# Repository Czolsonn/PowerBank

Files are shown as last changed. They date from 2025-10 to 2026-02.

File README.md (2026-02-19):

# STM32 Solar PowerBank





Projekt inteligentnego PowerBanka sterowanego mikrokontrolerem z rodziny **STM32F1**, integrującego ładowanie fotowoltaiczne z zaawansowanym zarządzaniem energią.

## 📋 Opis Projektu

Urządzenie łączy funkcję magazynu energii (ogniwa 18650) z inteligentnym systemem sterowania. Wykorzystuje synchroniczną przetwornicę Buck do efektywnego obniżania napięcia oraz dedykowane kontrolery USB do bezpiecznego ładowania urządzeń zewnętrznych.

### Kluczowe parametry techniczne
* **Mikrokontroler:** STM32F1xx (zarządzanie PWM, pomiary ADC, komunikacja).
* **Wejście:** Obsługa paneli fotowoltaicznych i zewnętrznych źródeł DC.
* **Wyjście:** Porty USB sterowane przez układy TPS25810 oraz TPS2514.
* **Pomiary:** Monitorowanie prądu za pomocą wzmacniacza INA180A2.

## 📂 Struktura Projektu

Repozytorium jest podzielone na sekcje sprzętową, programową oraz dokumentacyjną:

```text
.
├── 📂 Dokumentacja_peryferiów  # Noty katalogowe i opisy układów (TPS, INA, LM)
├── 📂 Obudowa_Schemat          # Pliki projektowe obudowy i poglądowe schematy
├── 📂 PowerBank_KICAD          # Projekt PCB w programie KiCad
│   ├── 📂 production           # Pliki produkcyjne (Gerber, BOM, OZE_PowerBank)
│   └── 📂 backups              # Kopie zapasowe projektu elektroniki
└── 📂 STM_C                    # Warstwa oprogramowania (Firmware)
    └── 📂 PowerBank            # Główny projekt STM32CubeIDE
        ├── 📂 Core             # Kod źródłowy aplikacji (Inc, Src, Startup)
        ├── 📂 Drivers          # Biblioteki HAL i CMSIS
        └── 📂 Debug            # Pliki binarne i logi kompilacji

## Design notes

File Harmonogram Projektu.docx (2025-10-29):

Harmonogram Projektu - PowerBank

1. Schemat układu wraz z doborem elementów wraz z symulacjami – (28.10 - 5.11)
2. Schemat PCB – (5.11 – 12.11) – zamówienie elementów i płytki
3. Oprogramowanie STM32 – (26.11 – 3.12)
4. Lutowanie układu i zgrzewanie ogniw (10.12 – 17.12)
5. Projekt i druk obudowy (07.01)
6. Dokumentacja i złożenie wszystkiego w całość wraz z testami (18.01)

Hubert Polus 278308

Michał Zawada

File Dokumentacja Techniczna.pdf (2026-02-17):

## Dokumentacja Powerbanka

Michał Zawada, Hubert Polus

3 lutego 2026

## Spis treści

1 Założenia projektowe | 3
2 Zdjęcie urządzenia | 3
3 Panel Fotowoltaiczny | 3
4 Schematy i opis poszczególnych funkcjonalnych elementów składowych. | 3

4.2 LM5106 - sterownik bramek MOSFET typu N do synchronicznego konwer-

4.5.1 | TPS2514ADBVT – kontroler dedykowanego portu ładowania USB . | 6
4.5.2 | TPS25810RVCR – kontroler portu USB z funkcją ładowania . . . . | 6
5 Przepływ Energii w układzie | 7
6 PCB | | 7
7 Algorytm sterowania | 8
8 Obliczenia | 10
9 Weryfikacja eksperymentalna układu | 11
10 Budżet Projektu | 13

11 Wnioski końcowe | 13
12 Linki i inspiracje | 14

## 1 Założenia projektowe

- Główna funkcja urządzenia: przenośne źródło zasilania dla urządzeń USB, ładowanie w standardzie BC1.2 z wyprowadzonym złączem USB A oraz USB C.
- Moduły: panel solarny, buck converter, procesor STM32F103C8Tx, TPS25810RVCR USB charging module, układ BMS, zewnętrzne przetwronice DC-DC.

## 2 Zdjęcie urządzenia

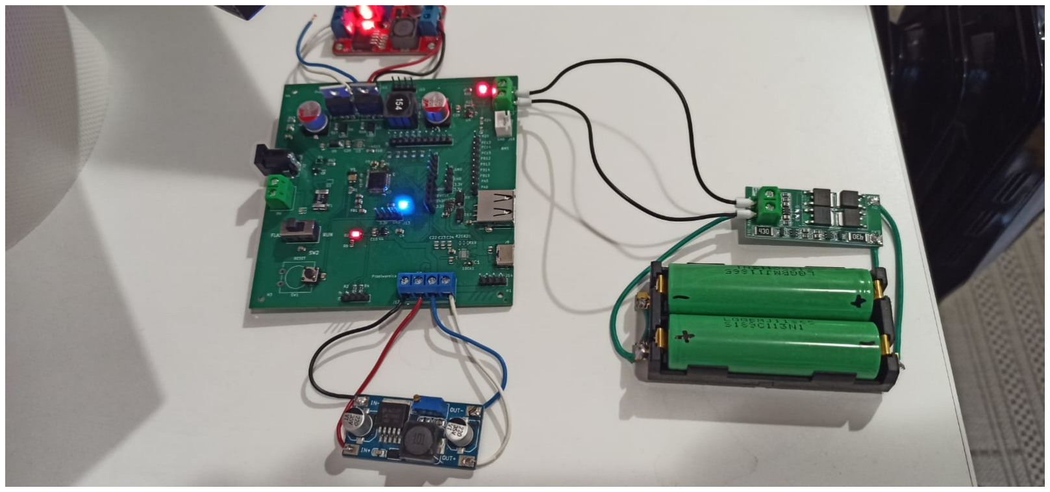
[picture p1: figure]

Rysunek 1: PowerBank - zaprojektowana płytka wraz z przetwornicami i pakietem ogniw.

## 3 Panel Fotowoltaiczny

Poniżej podane zostały główne parametry panelu fotowoltaicznego który zostanie wykorzystany w projekcie.

- P = 5W
- Impp = 0.3A
- Vmpp = 16.8V
- Isc = 0.34A
- Voc = 21.0V

## 4 Schematy i opis poszczególnych funkcjonalnych ele-

mentów składowych.

### 4.1 Buck Converter - Przetwornica Synchroniczna

- Vin = 15 − 30V

- IinMAX = 0.5A
- PWM Frequency fs = 100kHz
- Algorytm sterowania iteracyjny na STM32.
- Vout = 8.4V oddawane do BMS.
- PinMAX = 15W

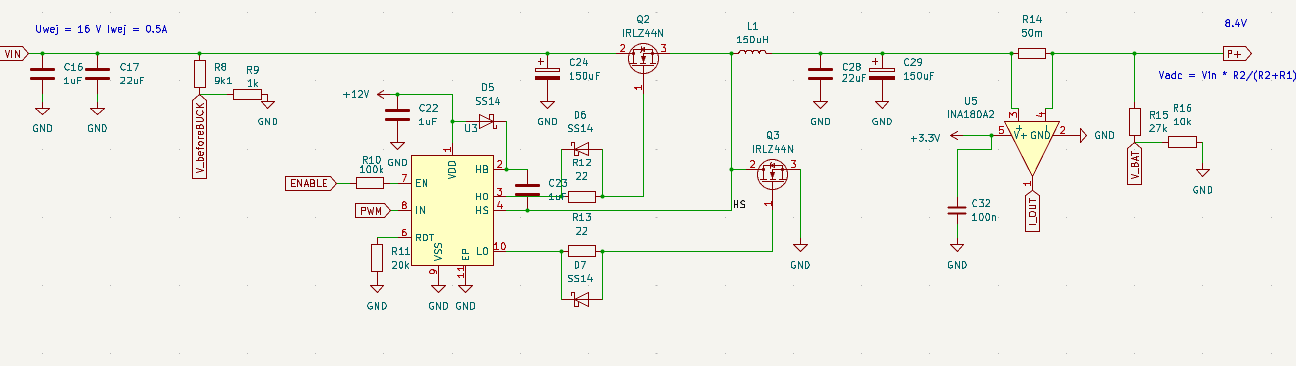
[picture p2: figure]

Rysunek 2: Schemat układu przetwornicy

Układy scalone zastosowane w układzie przetwornicy synchronicznej

### 4.2 LM5106 - sterownik bramek MOSFET typu N do synchro-

nicznego konwertera obniżającego napięcie

LM5106 jest dwukanałowym sterownikiem bramek tranzystorów MOSFET typu highside oraz low-side, przeznaczonym do zastosowań w impulsowych układach zasilania. Układ umożliwia sterowanie parą tranzystorów MOSFET za pomocą pojedynczego sygnału PWM oraz zapewnia automatyczne generowanie odpowiedniego czasu martwego (dead-time) pomiędzy przełączeniami tranzystorów. W realizowanym projekcie LM5106 został zastosowany jako element sterujący synchronicznym przekształtnikiem obniżającym napięcie typu buck (step-down).

### 4.3 INA180A2 - wzmacniacz operacyjny do pomiarów prądu

INA180A2 jest układem przeznaczonym do pośredniego pomiaru prądu poprzez wzmacnianie spadku napięcia odkładającego się na rezystorze pomiarowym (shunt). W omawianej wersji układu zastosowano wzmocnienie równe 20 V/V, natomiast na jego wyjściu dostępny jest analogowy sygnał napięciowy proporcjonalny do mierzonego prądu.

### 4.4 Schemat STM32

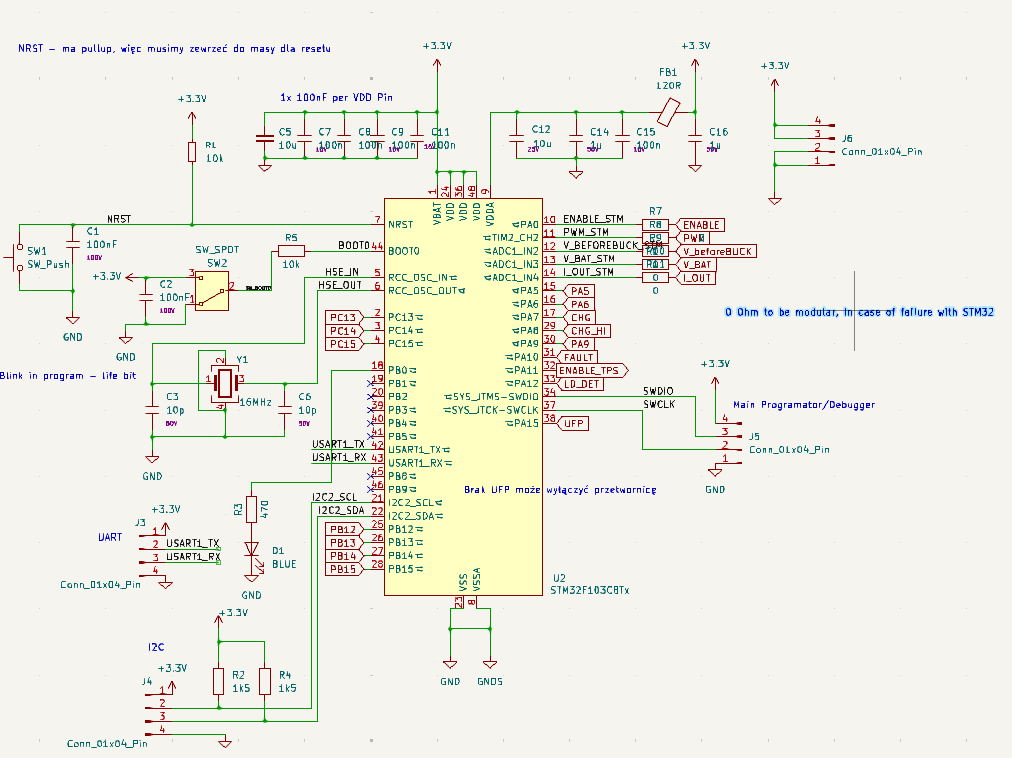
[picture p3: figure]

Rysunek 3: Schemat części dotyczącej mikrokontrolera STM32.

4.4.1 Opis części układu związanej z mikroprocesorem.

W projekcie wykorzystano mikroprocesor STM32F103C8Tx. Dołożono zewnętrzny rezonator kwarcowy oraz przycisk do resetu i wyboru FLASH/RUN. Aby sygnalizować pracę i wykonywanie programu, dołożono diodę niebieską LED, która miga z okresem T=1s. Programowanie płytki PowerBank umożliwia interfejs SWD ST-LINK/V2, którego piny zostały wyprowadzone na płytce. Większość pinów mikrokontrolera została wyprowadzona w celu umożliwienia debugowania - sygnały związane z kontrolerem ładowania portu USB, przetwornicą oraz pozostałe, które mogą zostać użyte do rozbudowania funkcjonalności układu.

4.5

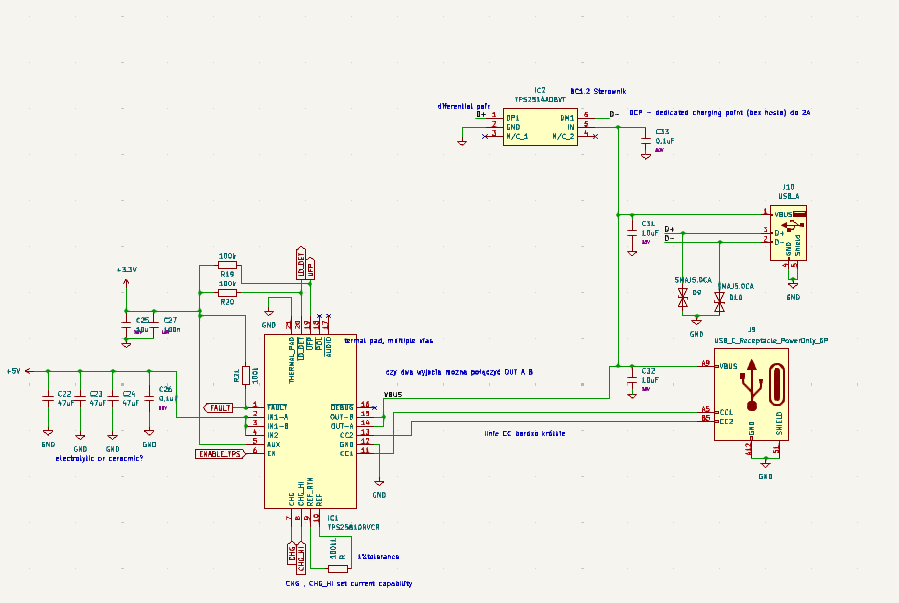
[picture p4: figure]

Rysunek 4: Schemat części dotyczącej układów ładowania USB

Opis zastosowanych układów scalonych.

### 4.5.1 TPS2514ADBVT – kontroler dedykowanego portu ładowania USB

Układ TPS2514ADBVT jest kontrolerem przeznaczonym do implementacji dedykowanego portu ładowania (DCP) zgodnego ze standardem USB BC1.2. Jego głównym zadaniem jest odpowiednia konfiguracja linii danych, tak aby podłączone urządzenie (np. smartfon lub tablet) mogło rozpoznać port jako port ładowania o podwyższonej wydajności prądowej.

### 4.5.2 TPS25810RVCR – kontroler portu USB z funkcją ładowania

Układ TPS25810RVCR firmy Texas Instruments jest zintegrowanym kontrolerem portu USB, przeznaczonym głównie do zastosowań w systemach zasilania i ładowania urządzeń przenośnych. Układ ten obsługuje standard USB Battery Charging (BC1.2), umożliwiając automatyczne rozpoznawanie typu podłączonego urządzenia oraz dostosowanie dopuszczalnego prądu ładowania.
TPS25810 zawiera wbudowany przełącznik mocy, zabezpieczenia nadprądowe, nadnapięciowe oraz termiczne, co pozwala na bezpieczne zasilanie urządzeń USB bez konieczności stosowania dodatkowych elementów ochronnych. Układ może pracować w trybie autonomicznym lub być sterowany przez mikrokontroler za pomocą interfejsu I²C, co umożliwia monitorowanie stanu portu oraz dynamiczne zarządzanie zasilaniem.
Do wyjść cyfrowych zastosowano odpowiednie rezystory podciągające zgodne z dokumentacją oraz dodano kondensatory odsprzęgające.

## 5 Przepływ Energii w układzie

- Schemat przepływu energii: Panel fotowoltaiczny → Buck converter → BMS → Ogniwo LiPol → Przetwornica Step-Down → port USB.

## 6 PCB

### 6.1 Zastosowanie ścieżek o zróżnicowanej szerokości

W projekcie płytki drukowanej zastosowano ścieżki o różnych szerokościach, w zależności od pełnionej funkcji elektrycznej. Ścieżki zasilające oraz linie przenoszące większe prądy zostały zaprojektowane o zwiększonej szerokości w celu ograniczenia spadków napięcia oraz strat mocy. Linie sygnałowe, w tym sygnały sterujące i komunikacyjne, prowadzone są węższymi ścieżkami, co pozwala na efektywne wykorzystanie powierzchni PCB oraz zachowanie odpowiednich odstępów izolacyjnych.

### 6.2 Struktura czterowarstwowej płytki PCB

Płytka została zaprojektowana jako czterowarstwowa, co umożliwiło poprawę integralności sygnałów oraz uporządkowanie dystrybucji zasilania.

### 6.3 Podział funkcjonalny płytki

Układ elementów na PCB został wykonany z zachowaniem podziału funkcjonalnego. Poszczególne bloki, takie jak sekcja zasilania, kontroler portu USB, przetwornica oraz złącza wyjściowe, zostały rozłożone w sposób minimalizujący długości ścieżek, ale pozwalający podzielić płytkę na części funkcjonalne.

### 6.4 Zastosowanie rezystorów 0

W projekcie wykorzystano rezystory 0 pełniące rolę konfiguracyjną. Elementy te umożliwiają odlutowanie sygnałów sterujących od mikroprocesora i sterowanie przetwornicą z zewnętrznego układu.

6.5 Odpowiednie poprowadzenie linii różnicowych.

Linie USB D+ i D zostały poprowadzone jako para różnicowa, z zachowaniem jednakowej długości, stałej szerokości ścieżek oraz kontrolowanego odstępu pomiędzy nimi. Ścieżki te prowadzone są nad ciągłą płaszczyzną masy, bez przerw w płaszczyźnie, co zapewnia kontrolę impedancji oraz minimalizację odbić i przesłuchów. Unikano ostrych zakrętów oraz niepotrzebnych przelotek na trasie sygnałów.

## 7 Algorytm sterowania

### 7.1 Konfiguracja mikrokontrolera w środowisku STM32CubeMX

Wstępna konfiguracja warstwy sprzętowej mikrokontrolera STM32F103C8Tx została zrealizowana przy użyciu oprogramowania STM32CubeMX. Schemat wyprowadzeń (pinout) układu przedstawiono na Rysunku 5

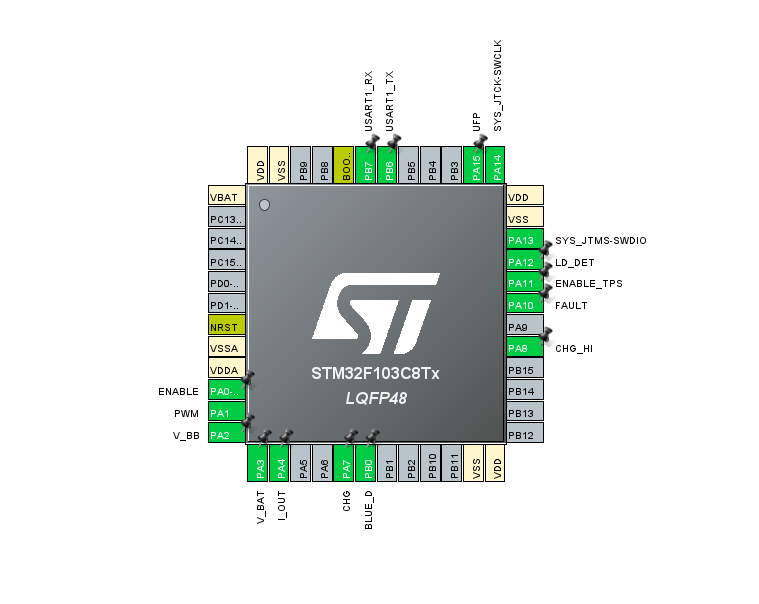
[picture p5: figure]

Rysunek 5: Pinout

Do kluczowych ustawień konfiguracyjnych projektu należą:

- System zegarowy: Jako źródło sygnału taktującego wybrano wewnętrzny oscylator RC (HSI – High Speed Internal). Decyzja ta podyktowana była ograniczeniami sprzętowymi dotyczącymi zewnętrznego rezonatora kwarcowego. Częstotliwość zegara systemowego (SYSCLK) została ustalona na poziomie 64 MHz z wykorzystaniem pętli fazowej PLL (Phase Locked Loop). Schemat drzewa zegarowego widoczny jest na Rysunku 6.
- Modulacja PWM: Timer sterujący generacją sygnału PWM skonfigurowano na częstotliwość pracy 100 kHz. Przy przyjętym taktowaniu rdzenia pozwoliło to na uzyskanie rozdzielczości wypełnienia wynoszącej 640 kroków.
- Przetwornik ADC: Akwizycja danych analogowych realizowana jest z wykorzystaniem mechanizmu bezpośredniego dostępu do pamięci (DMA) w trybie ciągłym (Continuous Conversion Mode). Dobrano następujące czasy próbkowania dla mierzonych wielkości fizycznych:

– Napięcie wejściowe i wyjściowe przetwornicy: 55.5 cykli zegara.
– Prąd wyjściowy przetwornicy: 239.5 cykli zegara.

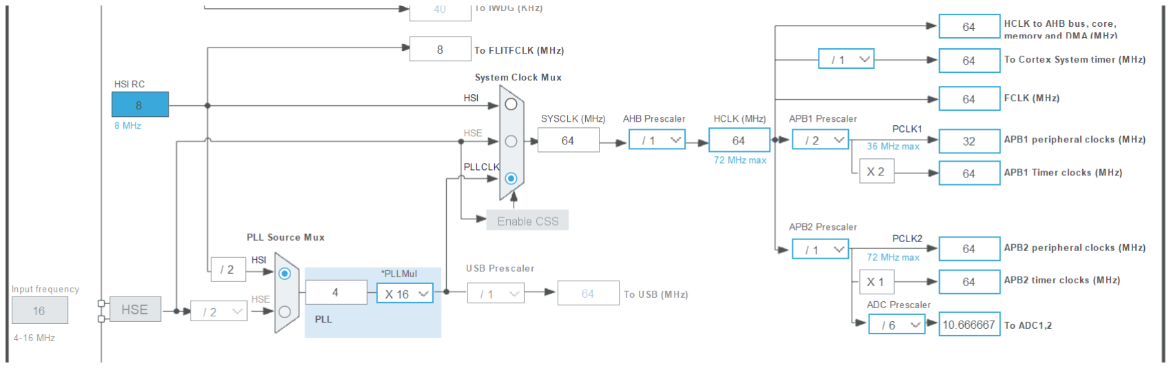
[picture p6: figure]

Rysunek 6: Taktowanie procesora

### 7.2 Implementacja oprogramowania w środowisku STM32CubeIDE

Kod źródłowy sterujący procesem ładowania ogniw oraz zarządzający układem peryferyjnym został zaimplementowany w środowisku STM32CubeIDE. Architektura oprogramowania opiera się na cyklicznym wykonywaniu zadań w dwóch głównych domenach czasowych:

1. Pętla sterowania i logiki (100 Hz) – odpowiedzialna za krytyczne procesy obliczeniowe i decyzyjne.
2. Pętla interfejsu i diagnostyki (1 Hz) – realizująca zadania o niższym priorytecie czasowym (sygnalizacja, komunikacja).

Szczegółowy opis procesów pętli głównej (100 Hz)

W ramach pętli szybkiej realizowane są dwa kluczowe bloki funkcjonalne:

1. Akwizycja i kondycjonowanie sygnałów pomiarowych (ADC) Proces ten składa się z trzech etapów zapewniających stabilność odczytów:
- Wyznaczenie średniej arytmetycznej z bufora 20 próbek pomiarowych.
- Konwersja surowych danych na jednostki fizyczne (skalowanie napięć i prądów).
- Filtracja cyfrowa z wykorzystaniem filtru dolnoprzepustowego o nieskończonej odpowiedzi impulsowej – wykładniczej średniej kroczącej (EMA).
2. Algorytm sterowania i bezpieczeństwa Logika sterująca pracą ładowarki oparta jest na:
- Weryfikacji zabezpieczeń: Ciągłe monitorowanie przekroczenia wartości granicznych dla napięcia (OVP) oraz prądu (OCP) w celu ochrony układu i ogniwa.
- Maszynie Stanów (FSM): Automatyczne przełączanie trybów pracy układu w zależności od warunków panujących w obwodzie. Zaimplementowane stany to: IDLE (oczekiwanie), SOFT START (łagodny rozruch), CHARGING (ładowanie właściwe wraz z algorytmem MPPT) oraz ERROR (stan błędu).

Szczegółowy opis pętli pomocniczej (1 Hz)

Pętla wolna odpowiada za interakcję z użytkownikiem oraz nadzór nad procesem:

- UART: Cykliczna transmisja danych diagnostycznych (monitorowanie napięć, prądów oraz mocy chwilowej) do terminala zewnętrznego.
- Sygnalizacja stanu: Obsługa diod LED informujących o statusie pracy urządzenia.

## 8 Obliczenia

### 8.1 Dobór ogniw

- Pojemność ogniwa: 3000 mAh
- Napięcie ogniwa: 3.7 V
- Wybrana konfiguracja: 2s

W ramach testów i programowania urządzenia pracowano w konfiguracji 2s.

### 8.2 Obliczenia buck convertera

Założenia:

- Częstotliwość PWM fs = 100 kHz
- Napięcie wejściowe Vin = 15-30 V
- Napięcie wyjściowe Vout = 8,4 V

Obliczenia:

L =

Vout∗(Vin−Vout)
∆IL∗fs∗Vin

=

8,4∗(30−8,4)
0,5∗10⁵∗30 = 120, 96µH

Dobrano : L = 150µH

C =

∆IL
8∗fs∗∆Vout

=

0.5
8∗10⁵∗50∗10⁻³ = 12, 5µF

Dobrano: C = 22µF

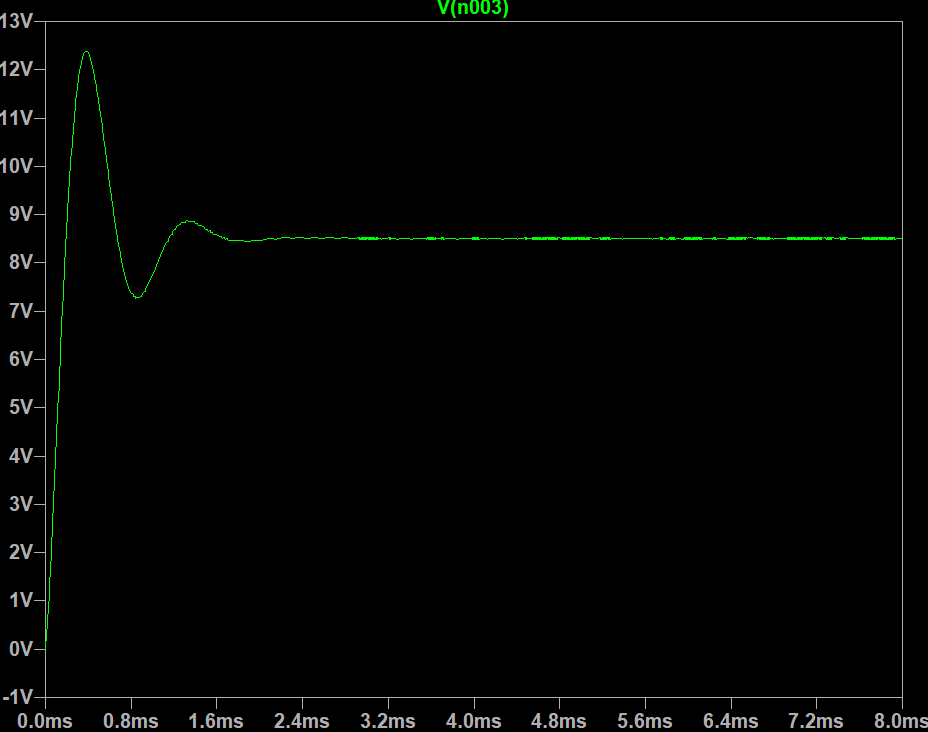
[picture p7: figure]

Rysunek 7: Symulacja dla przetwornicy obniżającej napięcie

- Pomiar napięcia wejściowego Vin na dzielniku napięcia 1kΩ|9kΩ dla Vin = 30V

Vzm = Vin ∗

R1
R2+R1

= 3V < 3, 3V
Izm =

Vin
R1+R2

= 3mA

- Pomiar prądu na RSHUNT = 50mΩ, 0,5 W za pomocą wzmacniacza INA180A1 20V/V
przy Vin = 30V , Vout = 8, 4V , η = 100% , Pin = 15W
Izm =

Pin
Vout∗η

= 1, 79A

VRSHUNT = RSHUNT ∗ Izm = 89, 5mV
Vzm = VRSHUNT ∗ 20 = 1, 79V < 3, 3V
PRSHUNT = VRSHUNT ∗ Izm = 0, 161W < 0, 5W
- Pomiar napięcia na ogniwach/wyjściowe przetwornicy na dzielniku 27kΩ|10kΩ dla Vout = 8,4V

Vzm = Vin ∗

R1
R2+R1

= 2, 27V < 3, 3V
Izm =

Vin
R1+R2

= 0, 23mA

- W układzie buck convertera za kondensatorem 22µF został umieszczony kondensator elektrolityczny 150µF o niskim ESR w celu poprawy charakterystyki napięciowej układu

## 9 Weryfikacja eksperymentalna układu

Celem przeprowadzonych testów była weryfikacja poprawności działania warstwy sprzętowej (układów pomiarowych napięcia i prądu) oraz ocena efektywności zaimplementowanego algorytmu śledzenia punktu mocy maksymalnej (MPPT).

Badania przeprowadzono w warunkach rzeczywistych, wykorzystując panel fotowoltaiczny eksponowany na promieniowanie słoneczne. Zmierzone napięcie obwodu otwartego (VOC) panelu w warunkach testowych wynosiło od 21 V do 22 V.

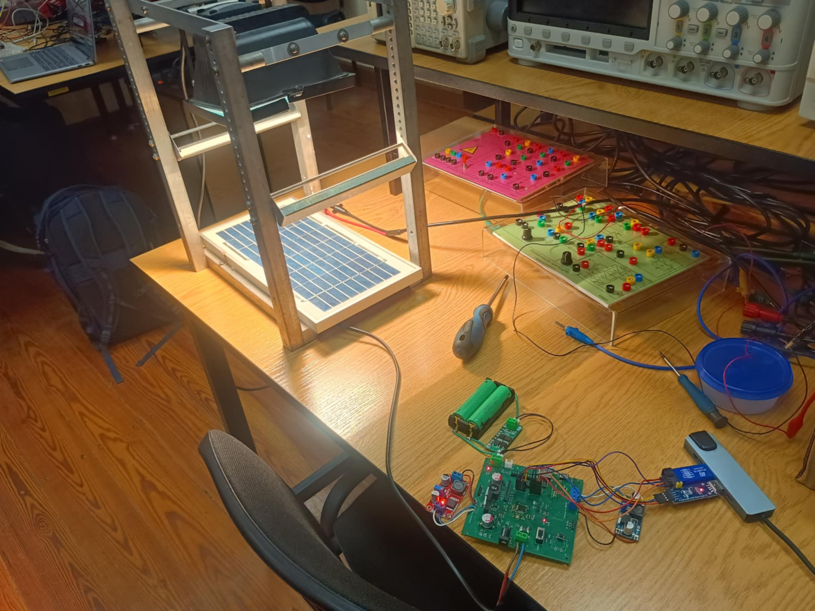
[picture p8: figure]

Rysunek 8: Stanowisko testowe z naświetlonym panelem fotowoltaicznym

W trakcie procesu ładowania zarejestrowano kluczowe parametry pracy przetwornicy, które przedstawiono na poniższym zdjęciu danych pomiarowych.

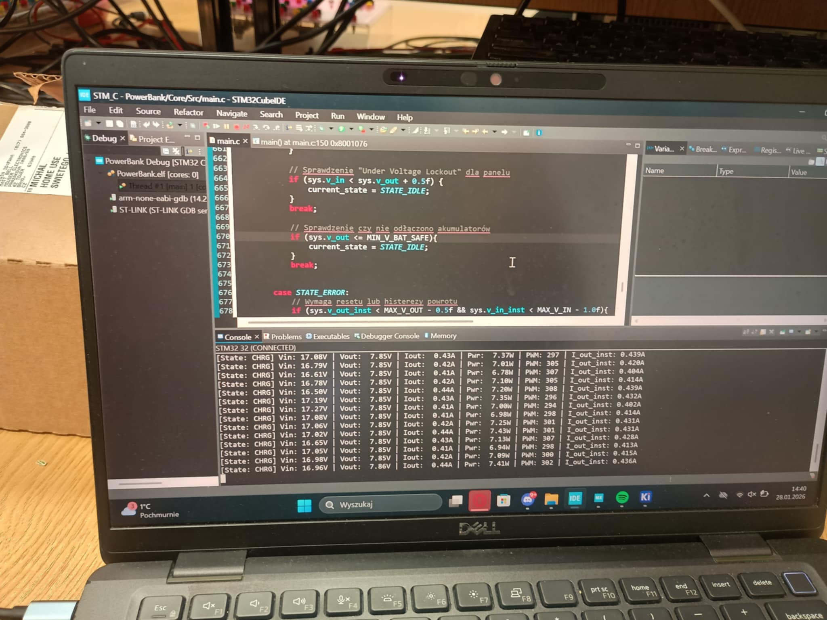
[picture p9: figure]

Rysunek 9: Zarejestrowane dane pomiarowe podczas pracy algorytmu MPPT

Analiza wyników potwierdziła poprawne działanie pętli regulacji. Algorytm MPPT pomyślnie zidentyfikował punkt mocy maksymalnej (VMP P ), stabilizując napięcie wejściowe przetwornicy na poziomie około 17 V. W tym punkcie pracy uzyskano prąd ładowania ogniwa o wartości Iout ≈ 400 mA.
Moc użyteczna przekazywana do obciążenia (moc wyjściowa) została wyznaczona na podstawie iloczynu napięcia i prądu wyjściowego:
Pout ≈ Vout · Iout ≈ 3.4 W | (1)

Uzyskany wynik świadczy o prawidłowym dopasowaniu impedancji obciążenia do źródła przez algorytm sterujący oraz o poprawnej pracy stopnia mocy przetwornicy.

## 10 Budżet Projektu

Zakładany budżet na projekt 400 zł. Część elementów - programator, złącza, kable nie będą kupowane.

- Ogniwa 18650 x4, przetwornice zewnętrzne DC-DC, uchwyt na baterie 18650 74 zł.
- Układ BMS 10 zł.
- Elementy elektroniczne z Mouser Electronics, dwa komplety 257 zł.
- Wyprofukowanie 5 płytek wraz z częściowym montażem przez JLCPCB 104 zł

Podsumowując, całkowity koszt wykonania projektu wyniósł 445 zł. Lekko przekroczyliśmy zakładany budżet.

## 11 Wnioski końcowe

- Montaż niektórych elementów przez JLCPCB był dobrym pomysłem. Usługa ta nie była droga, a zaoszczędziła wiele pracy przy lutowaniu.
- Należy unikać obudów QFN, gdyż przytulanie elementów wymaga użycia Hot-Air i odpowiedniej kolejności lutowania. Po zostawieniu ich na koniec należy zabezpieczyć podczas lutowania inne elementy taśmą kaptonową, aby nie zostały nadtopione.
- Zaprogramowanie interfejsu UART i diód LED ułatwia orientację w tym, jaki jest stan układu i czy uC wykonuje program.
- Procesory STM32 są trudnym punktem wyjścia, wymagają wielu konfiguracji i programowania, aby cokolwiek na nich uruchomić. Na przyszłość zastosowalibyśmy inny układ, np. ESP32.
- Zastosowanie gotowych i sprawdzonych układów przetwornic oraz BMS znacznie uprościło projekt płytki.

## 12 Linki i inspiracje

- STM32 Official Site (https://www.st.com/en/microcontrollers-microprocessors/stm32.html)
- DigiKey Electronics (https://www.digikey.com/)
- Forbot (https://forbot.pl/)
- Projekty open-source powerbanków

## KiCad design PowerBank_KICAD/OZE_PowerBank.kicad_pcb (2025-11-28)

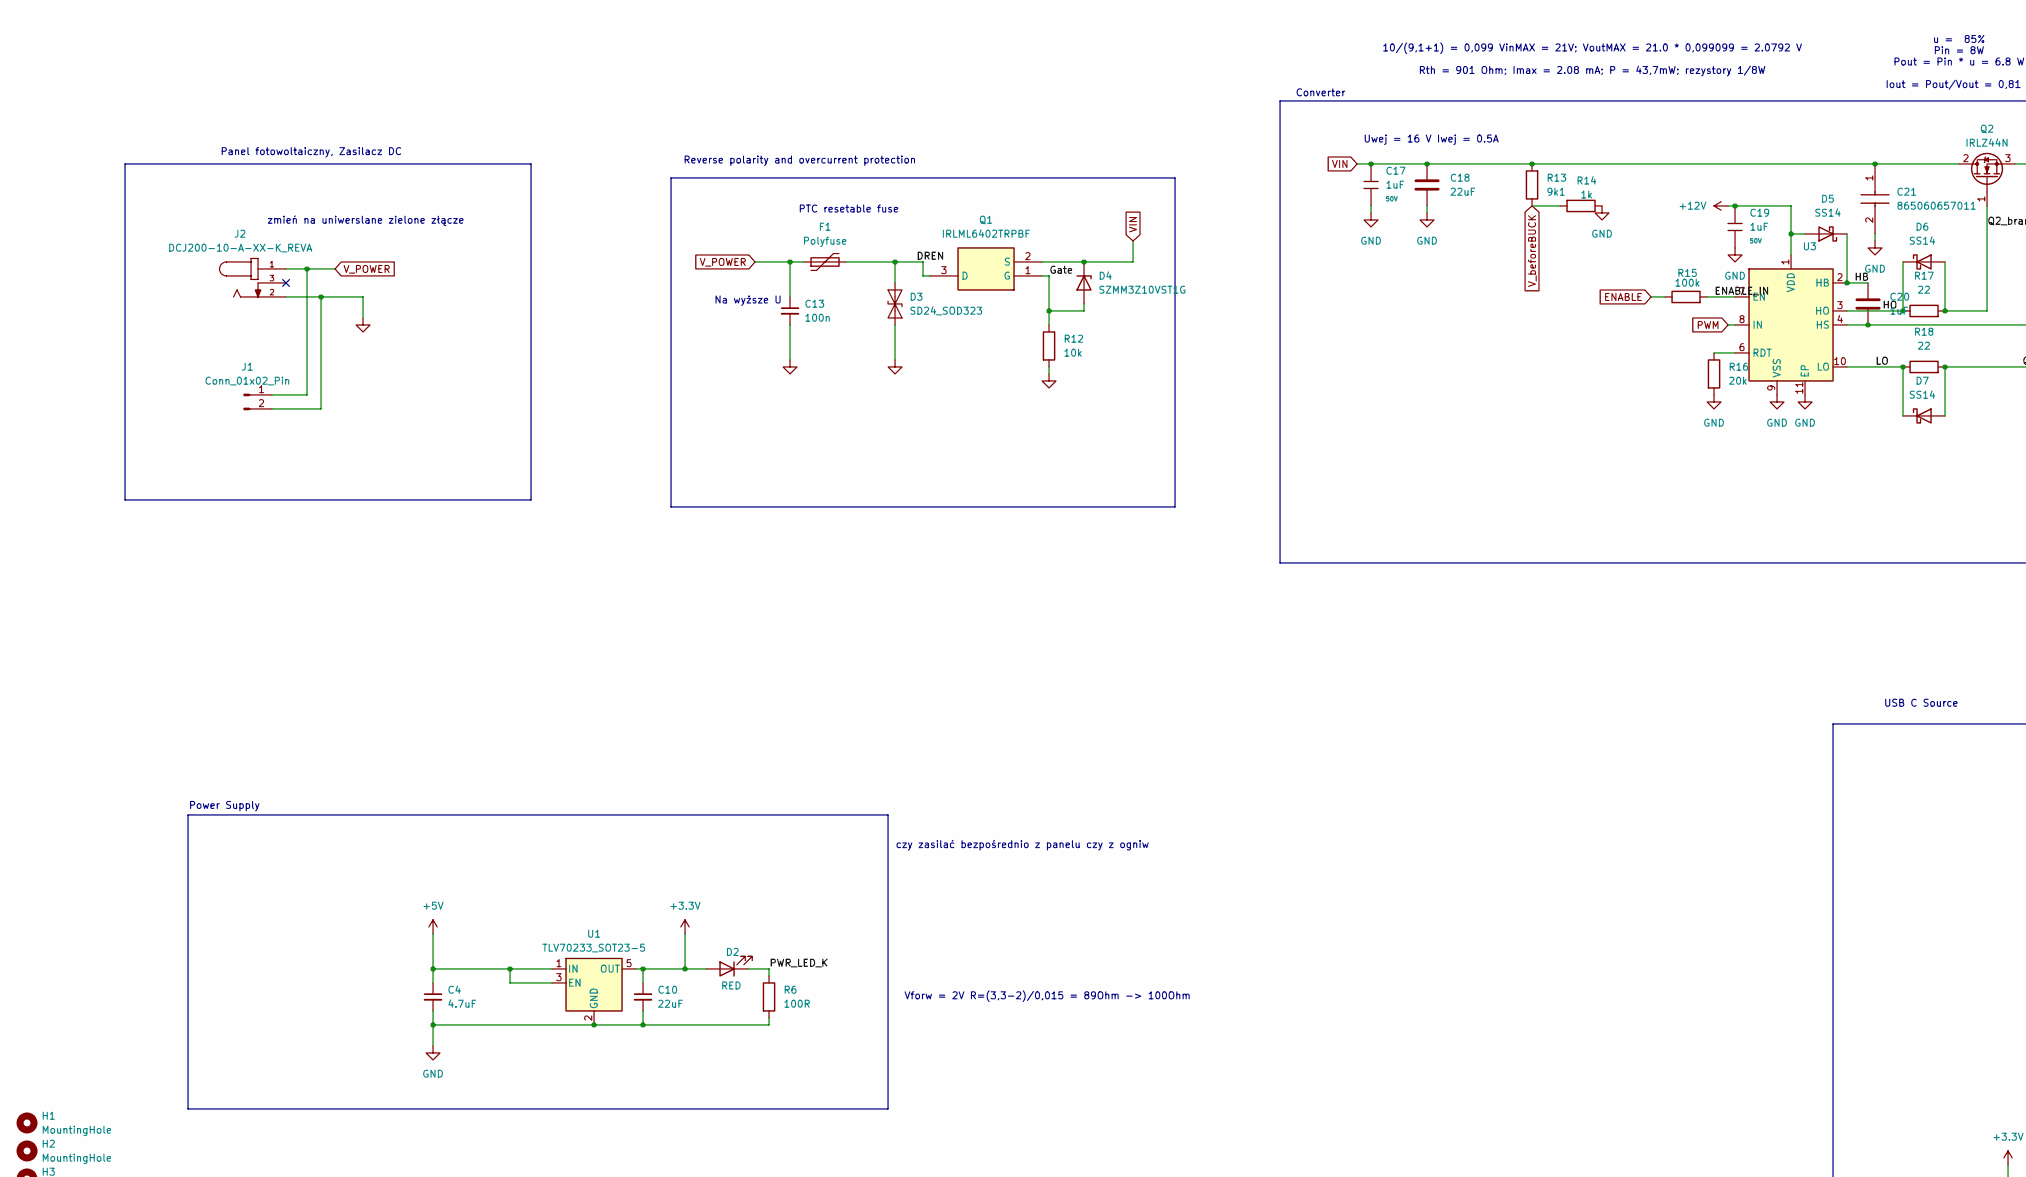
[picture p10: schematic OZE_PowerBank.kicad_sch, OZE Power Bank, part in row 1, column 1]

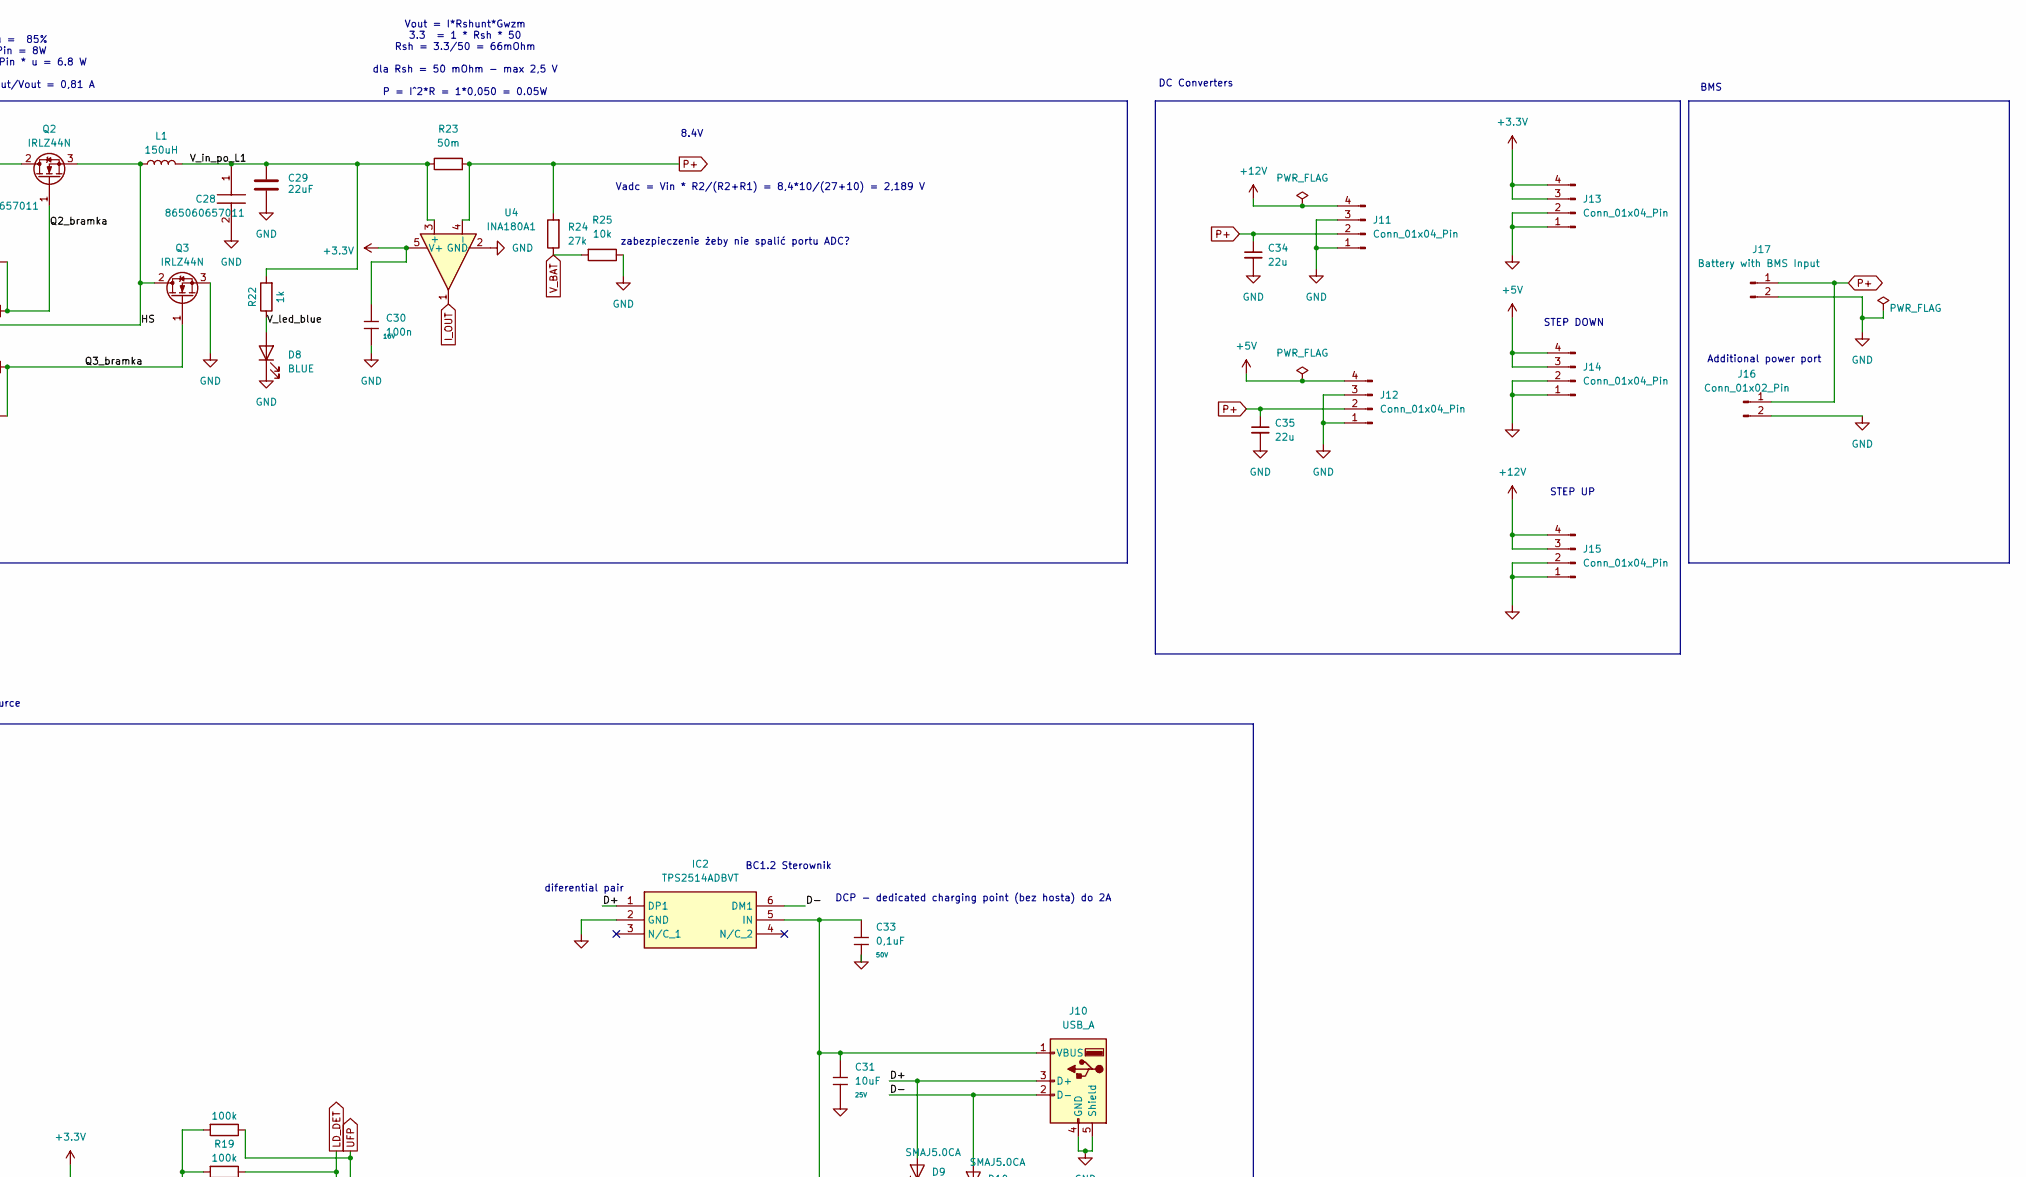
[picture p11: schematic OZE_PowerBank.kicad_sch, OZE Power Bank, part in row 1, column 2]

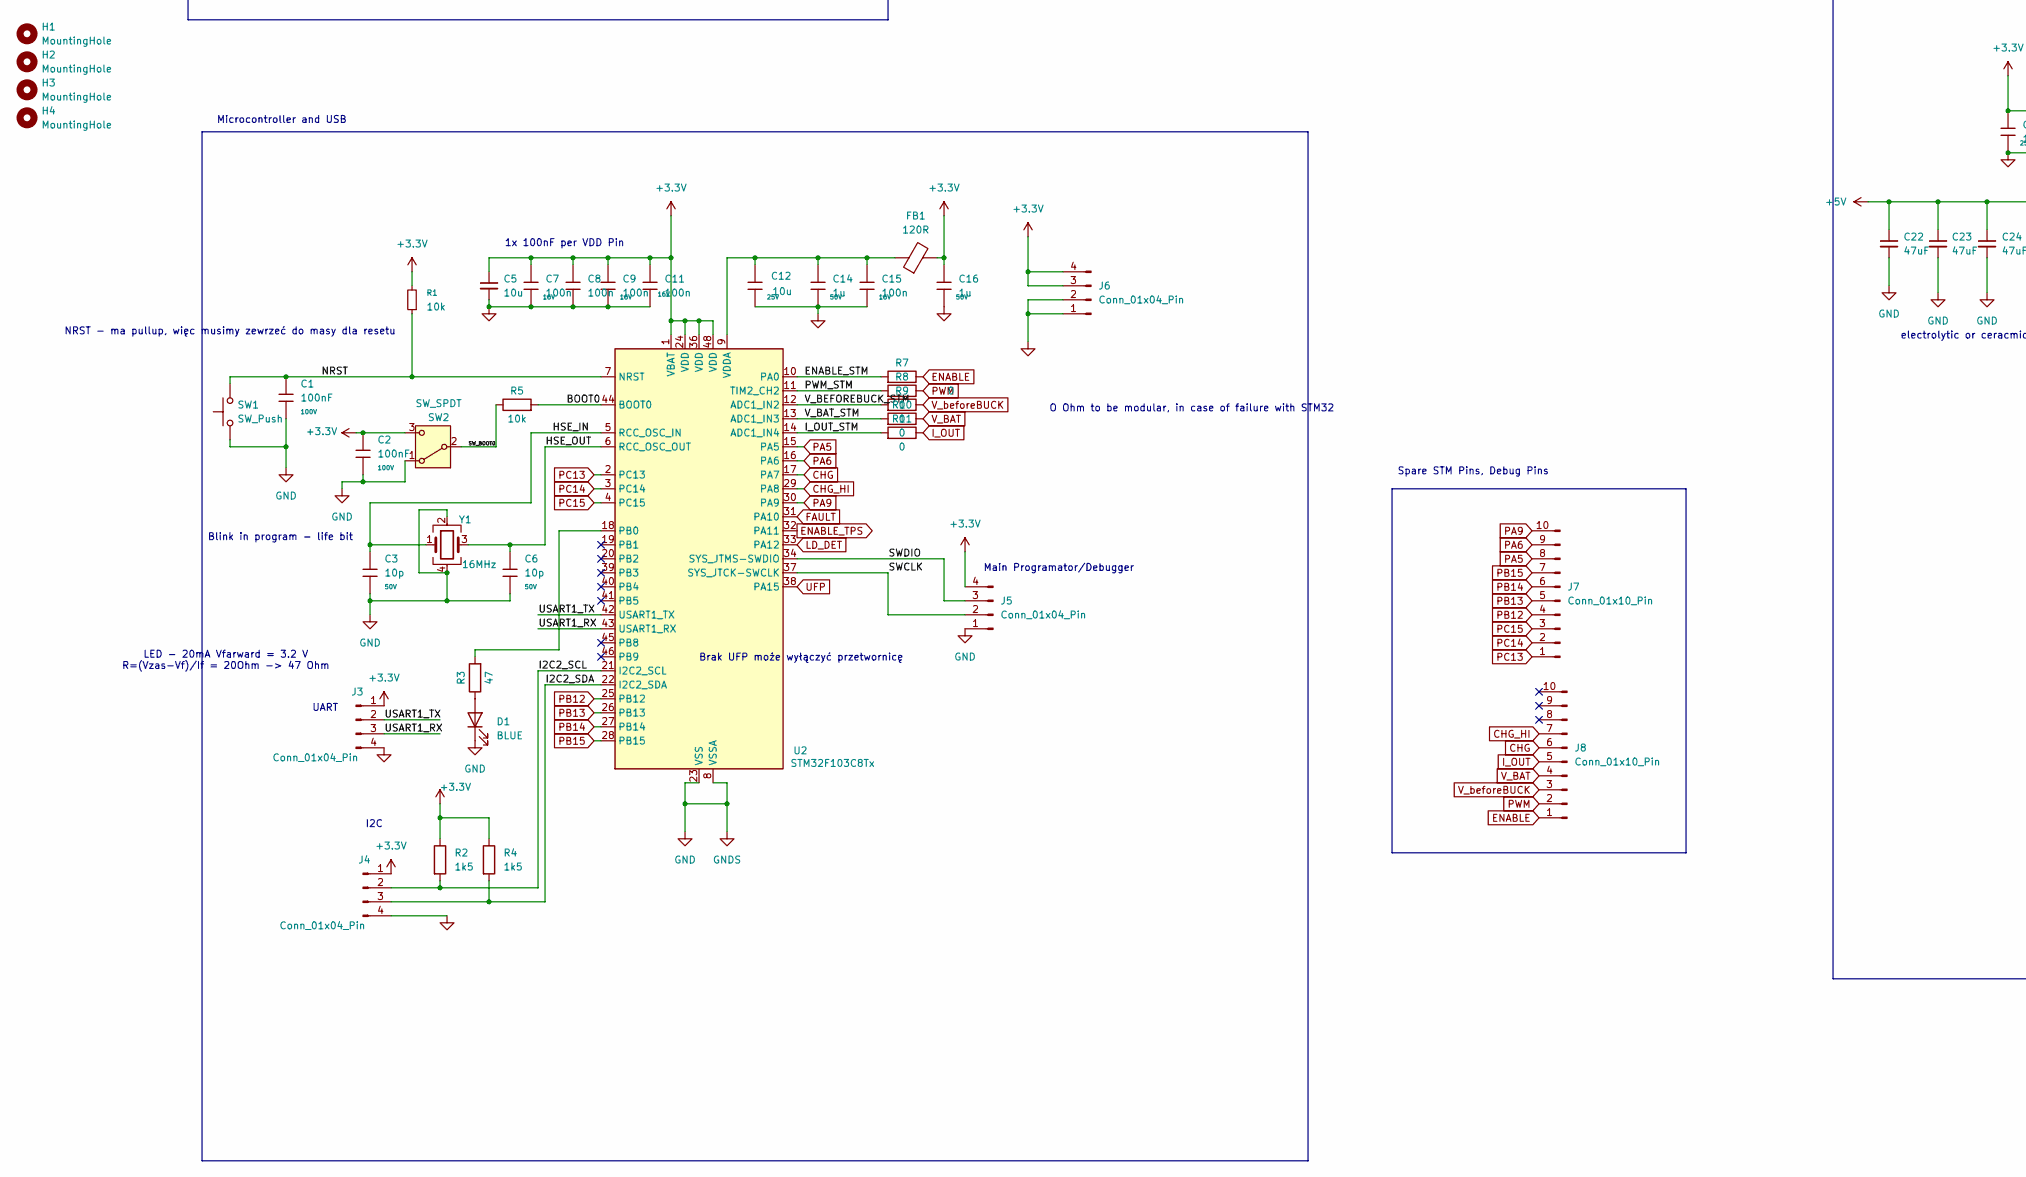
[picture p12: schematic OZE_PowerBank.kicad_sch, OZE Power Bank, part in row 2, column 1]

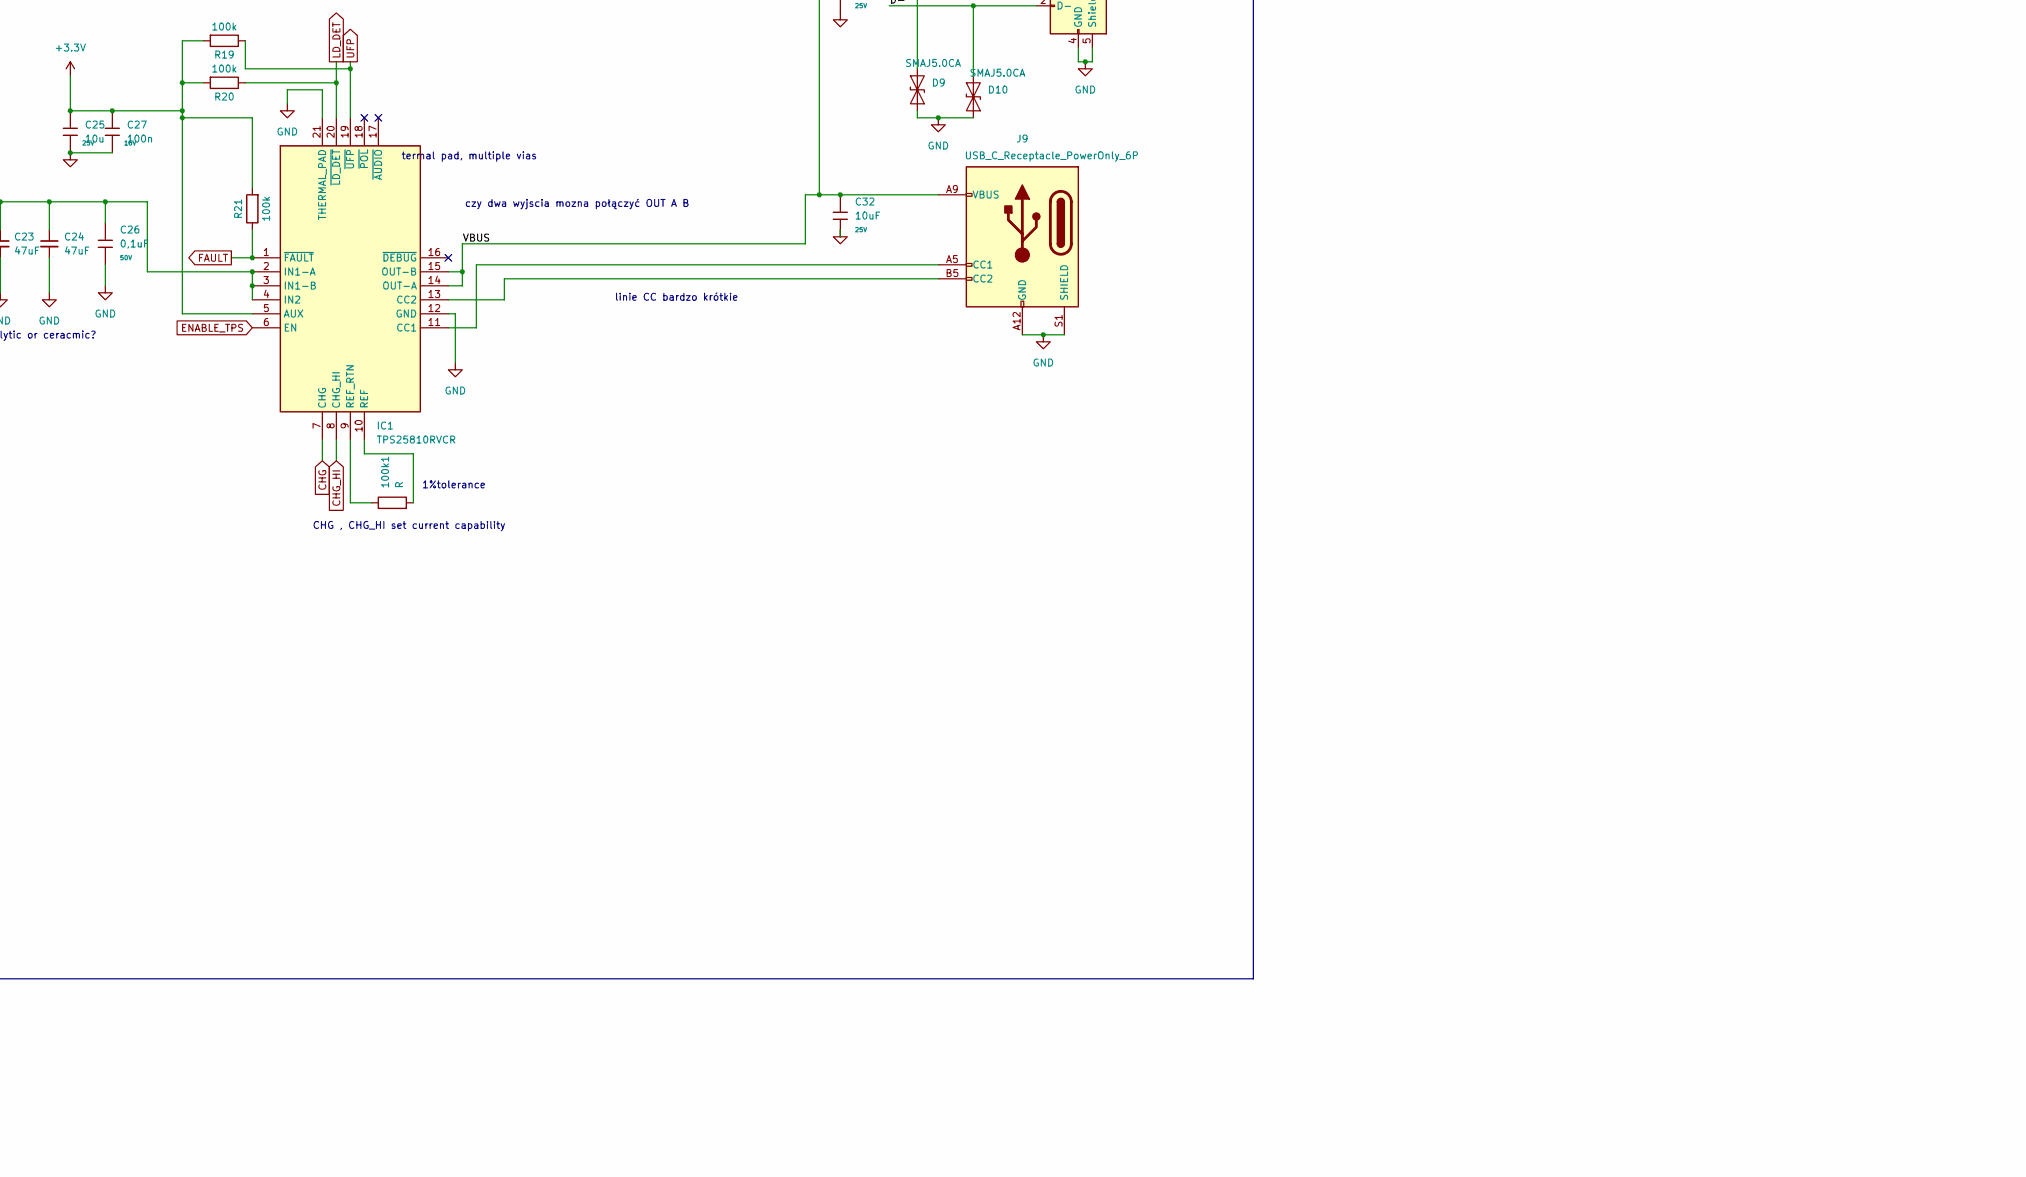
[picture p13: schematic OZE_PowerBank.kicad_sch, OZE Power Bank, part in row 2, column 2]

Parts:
100k1: R; R_0603_1608Metric_Pad0.98x0.95mm_HandSolder
C1, C2: 100nF; C_0805; Voltage Rated 100V; Tolerance ±10%; Part CL21B104KCFNNNE; LCSC C28233
C3, C6: 10p; C_0402; Voltage Rated 50V; Tolerance ±5%; Part CL05C100JB5NNNC; LCSC C32949
C4: 4.7uF; C_0805_2012Metric_Pad1.18x1.45mm_HandSolder
C5: 10u; C_0805_2012Metric_Pad1.18x1.45mm_HandSolder
C7, C8, C9, C11, C15, C27, C30: 100n; C_0402; Voltage Rated 16V; Tolerance ±10%; Part CL05B104KO5NNNC; LCSC C1525
C10, C18, C29: 22uF; C_0805_2012Metric_Pad1.18x1.45mm_HandSolder
C12, C25: 10u; C_0805; Voltage Rated 25V; Tolerance ±10%; Part CL21A106KAYNNNE; LCSC C15850
C13: 100n; C_0805_2012Metric
C14, C16: 1u; C_0805; Voltage Rated 50V; Tolerance ±10%; Part CL21B105KBFNNNE; LCSC C28323
C17, C19: 1uF; C_0805; Voltage Rated 50V; Tolerance ±10%; Part CL21B105KBFNNNE; LCSC C28323
C20: 1uF; C_0805_2012Metric_Pad1.18x1.45mm_HandSolder
C21, C28: 865060657011; CAPAE1030X1050N; Mouser Part Number 710-865060657011
C22, C23, C24: 47uF; C_0805_2012Metric_Pad1.18x1.45mm_HandSolder
C26, C33: 0,1uF; C_0805; Voltage Rated 50V; Tolerance ±10%; Part CL21B105KBFNNNE; LCSC C28323
C31, C32: 10uF; C_0805; Voltage Rated 25V; Tolerance ±10%; Part CL21A106KAYNNNE; LCSC C15850
C34, C35: 22u; C_0805_2012Metric_Pad1.18x1.45mm_HandSolder
D1, D8: BLUE; LED_1206_3216Metric_Pad1.42x1.75mm_HandSolder
D2: RED; LED_1206_3216Metric_Pad1.42x1.75mm_HandSolder
D3: SD24_SOD323; D_SOD-323
D4: SZMM3Z10VST1G; D_SOD-323
D5, D6, D7: SS14; D_SMA
D9, D10: SMAJ5.0CA; D_SMA
F1: Polyfuse; Fuse_2920_7451Metric_Pad2.10x5.45mm_HandSolder
FB1: 120R; R_0603_1608Metric_Pad0.98x0.95mm_HandSolder
H1, H2, H3, H4: MountingHole; MountingHole_2.2mm_M2_ISO7380
IC1: TPS25810RVCR; QFN50P300X400X80-21N; Mouser Part Number 595-TPS25810RVCR
IC2: TPS2514ADBVT; SOT95P280X145-6N; Mouser Part Number 595-TPS2514ADBVT
J1: Conn_01x02_Pin; TerminalBlock_Phoenix_PT-1,5-2-5.0-H_1x02_P5.00mm_Horizontal
J2: DCJ200-10-A-XX-K_REVA; BarrelJack_GCT_DCJ200-10-A_Horizontal; PARTREV A
J3, J4, J5, J6, J13, J14, J15: Conn_01x04_Pin; PinSocket_1x04_P2.54mm_Vertical
J7, J8: Conn_01x10_Pin; PinSocket_1x10_P2.54mm_Vertical
J9: USB_C_Receptacle_PowerOnly_6P; USB_C_Receptacle_GCT_USB4125-xx-x-0190_6P_TopMnt_Horizontal
J10: USB_A; USB_A_TE_292303-7_Horizontal
J11: Conn_01x04_Pin; TerminalBlock_Phoenix_PT-1,5-4-3.5-H_1x04_P3.50mm_Horizontal
J12: Conn_01x04_Pin; TerminalBlock_Phoenix_PT-1,5-4-5.0-H_1x04_P5.00mm_Horizontal
J16: Conn_01x02_Pin; JST_XH_B2B-XH-A_1x02_P2.50mm_Vertical
J17: Battery with BMS Input; TerminalBlock_Phoenix_PT-1,5-2-5.0-H_1x02_P5.00mm_Horizontal
L1: 150uH; L_Pulse_PA4320
Q1: IRLML6402TRPBF; SOT95P237X112-3N; Mouser Part Number 942-IRLML6402TRPBF
Q2, Q3: IRLZ44N; TO-220-3_Vertical
R1, R5, R12, R25: 10k; R_0805_2012Metric_Pad1.20x1.40mm_HandSolder
R2, R4: 1k5; R_0805_2012Metric_Pad1.20x1.40mm_HandSolder
R3: 47; R_0805_2012Metric_Pad1.20x1.40mm_HandSolder
R6: 100R; R_0805_2012Metric_Pad1.20x1.40mm_HandSolder
R7, R8, R9, R10, R11: 0; R_0805; Overload Voltage (Max) 150V; Tolerance ±1%; Part 0805W8F0000T5E; LCSC C17477
R13: 9k1; R_0805_2012Metric_Pad1.20x1.40mm_HandSolder
R14, R22: 1k; R_0805_2012Metric_Pad1.20x1.40mm_HandSolder
R15, R19, R20, R21: 100k; R_0402_1005Metric
R16: 20k; R_0805_2012Metric_Pad1.20x1.40mm_HandSolder
R17, R18: 22; R_0805_2012Metric_Pad1.20x1.40mm_HandSolder
R23: 50m; R_1206_3216Metric_Pad1.30x1.75mm_HandSolder
R24: 27k; R_0805_2012Metric_Pad1.20x1.40mm_HandSolder
SW1: SW_Push; SW_PUSH-12mm_Wuerth-430476085716
SW2: SW_SPDT; SLW12768644AD
U1: TLV70233_SOT23-5; SOT-23-5
U2: STM32F103C8Tx; LQFP-48_7x7mm_P0.5mm
U3: LM5106SD; WSON-10-1EP_4x4mm_P0.8mm_EP2.6x3mm_ThermalVias
U4: INA180A1; SOT-23-5
Y1: 16MHz; LFXTAL071744Reel

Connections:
+3.3V: C2.1, C5.1, C7.1, C8.1, C9.1, C10.1, C11.1, C16.1, C25.1, C27.1, C30.1, D2.2 (A), FB1.2, IC1.5 (AUX), J3.1, J4.1, J5.4, J6.3, J6.4, J13.3, J13.4, R1.2, R2.1, R4.1, R19.2, R20.2, R21.2, SW2.3 (C), U1.5 (OUT), U2.1 (VBAT), U2.24 (VDD), U2.36 (VDD), U2.48 (VDD), U4.5 (V+)
+5V: C4.1, C22.1, C23.1, C24.1, C26.1, IC1.2 (IN1-A), IC1.3 (IN1-B), IC1.4 (IN2), J12.4, J14.3, J14.4, U1.1 (IN), U1.3 (EN)
+12V: C19.1, D5.2 (A), J11.4, J15.3, J15.4, U3.1 (VDD)
/BOOT0: R5.2, U2.44 (BOOT0)
/D+: D9.1 (A1), IC2.1 (DP1), J10.3 (D+)
/D-: D10.1 (A1), IC2.6 (DM1), J10.2 (D-)
/DREN: D3.2 (A2), F1.2, Q1.3 (D)
/ENABLE_IN: R15.2, U3.7 (EN)
/ENABLE_STM: R7.1, U2.10 (PA0)
/Gate: D4.2 (A), Q1.1 (G), R12.1
/HB: C20.1, D5.1 (K), U3.2 (HB)
/HO: D6.1 (K), R17.1, U3.3 (HO)
/HS: C20.2, L1.1, Q2.3 (S), Q3.2 (D), U3.4 (HS)
/HSE_IN: C3.1, U2.5 (RCC_OSC_IN), Y1.1
/HSE_OUT: C6.1, U2.6 (RCC_OSC_OUT), Y1.3
/I2C2_SCL: J4.2, R2.2, U2.21 (I2C2_SCL)
/I2C2_SDA: J4.3, R4.2, U2.22 (I2C2_SDA)
/I_OUT_STM: R11.1, U2.14 (ADC1_IN4)
/LO: D7.1 (K), R18.1, U3.10 (LO)
/NRST: C1.1, R1.1, SW1.2, U2.7 (NRST)
/PWM_STM: R8.1, U2.11 (TIM2_CH2)
/PWR_LED_K: D2.1 (K), R6.1
/Q2_bramka: D6.2 (A), Q2.1 (G), R17.2
/Q3_bramka: D7.2 (A), Q3.1 (G), R18.2
/SWCLK: J5.2, U2.37 (SYS_JTCK-SWCLK)
/SWDIO: J5.3, U2.34 (SYS_JTMS-SWDIO)
/SW_BOOT0: R5.1, SW2.2 (B)
/USART1_RX: J3.3, U2.43 (USART1_RX)
/USART1_TX: J3.2, U2.42 (USART1_TX)
/VBUS: C31.2, C32.1, C33.1, IC1.14 (OUT-A), IC1.15 (OUT-B), IC2.5 (IN), J9.A9 (VBUS), J9.B9 (VBUS), J10.1 (VBUS)
/V_BAT_STM: R10.1, U2.13 (ADC1_IN3)
/V_BEFOREBUCK_STM: R9.1, U2.12 (ADC1_IN2)
/V_in_po_L1: C28.1 (+), C29.1, L1.2, R22.2, R23.1, U4.3 (+)
/V_led_blue: D8.2 (A), R22.1
CHG: IC1.7 (CHG), J8.6, U2.17 (PA7)
CHG_HI: IC1.8 (CHG_HI), J8.7, U2.29 (PA8)
ENABLE: J8.1, R7.2, R15.1
ENABLE_TPS: IC1.6 (EN), U2.32 (PA11)
FAULT: IC1.1 (~FAULT), R21.1, U2.31 (PA10)
GND: C1.2, C2.2, C3.2, C4.2, C5.2, C6.2, C7.2, C8.2, C9.2, C10.2, C11.2, C12.2, C13.2, C14.2, C15.2, C16.2, C17.2, C18.2, C19.2, C21.2 (-), C22.2, C23.2, C24.2, C25.2, C26.2, C27.2, C28.2 (-), C29.2, C30.2, C31.1, C32.2, C33.2, C34.2, C35.2, D1.1 (K), D3.1 (A1), D8.1 (K), D9.2 (A2), D10.2 (A2), IC1.12 (GND), IC1.21 (THERMAL_PAD), IC2.2 (GND), J1.2, J2.2, J3.4, J4.4, J5.1, J6.1, J6.2, J9.A12 (GND), J9.B12 (GND), J9.S1 (SHIELD), J10.4 (GND), J10.5 (Shield), J11.1, J11.3, J12.1, J12.3, J13.1, J13.2, J14.1, J14.2, J15.1, J15.2, J16.2, J17.2, Q3.3 (S), R6.2, R12.2, R14.1, R16.2, R25.1, SW1.1, SW2.1 (A), U1.2 (GND), U2.8 (VSSA), U2.23 (VSS), U2.35 (VSS), U2.47 (VSS), U3.9 (VSS), U3.11 (EP), U3.12, U4.2 (GND), Y1.2, Y1.4
I_OUT: J8.5, R11.2, U4.1
LD_DET: IC1.20 (~LD_DET), R20.1, U2.33 (PA12)
unnamed: D1.2 (A), R3.1
unnamed: IC1.11 (CC1), J9.A5 (CC1)
unnamed: IC1.13 (CC2), J9.B5 (CC2)
unnamed: 100k1.2, IC1.10 (REF)
unnamed: 100k1.1, IC1.9 (REF_RTN)
unnamed: R3.2, U2.18 (PB0)
unnamed: C12.1, C14.1, C15.1, FB1.1, U2.9 (VDDA)
unnamed: R16.1, U3.6 (RDT)
P+: C34.1, C35.1, J11.2, J12.2, J16.1, J17.1, R23.2, R24.2, U4.4 (-)
PA5: J7.8, U2.15 (PA5)
PA6: J7.9, U2.16 (PA6)
PA9: J7.10, U2.30 (PA9)
PB12: J7.4, U2.25 (PB12)
PB13: J7.5, U2.26 (PB13)
PB14: J7.6, U2.27 (PB14)
PB15: J7.7, U2.28 (PB15)
PC13: J7.1, U2.2 (PC13)
PC14: J7.2, U2.3 (PC14)
PC15: J7.3, U2.4 (PC15)
PWM: J8.2, R8.2, U3.8 (IN)
UFP: IC1.19 (~UFP), R19.1, U2.38 (PA15)
VIN: C17.1, C18.1, C21.1 (+), D4.1 (K), Q1.2 (S), Q2.2 (D), R13.2
V_BAT: J8.4, R10.2, R24.1, R25.2
V_POWER: C13.1, F1.1, J1.1, J2.1
V_beforeBUCK: J8.3, R9.2, R13.1, R14.2

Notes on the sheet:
STEP UP
zmień na uniwerslane zielone złącze
Blink in program - life bit
u = 85% Pin = 8W Pout = Pin * u = 6.8 W Iout = Pout/Vout = 0,81 A
NRST - ma pullup, więc musimy zewrzeć do masy dla resetu
diferential pair
Reverse polarity and overcurrent protection
Microcontroller and USB
Uwej = 16 V Iwej = 0.5A
STEP DOWN
DCP - dedicated charging point (bez hosta) do 2A
Spare STM Pins, Debug Pins
PTC resetable fuse
linie CC bardzo krótkie
O Ohm to be modular, in case of failure with STM32
CHG , CHG_HI set current capability
BC1.2 Sterownik
1x 100nF per VDD Pin
Vadc = Vin * R2/(R2+R1) = 8,4*10/(27+10) = 2,189 V
Brak UFP może wyłączyć przetwornicę
I2C
Na wyższe U
Vforw = 2V R=(3,3-2)/0,015 = 89Ohm -> 100Ohm
czy zasilać bezpośrednio z panelu czy z ogniw
LED - 20mA Vfarward = 3.2 V R=(Vzas-Vf)/If = 20Ohm -> 47 Ohm
zabezpieczenie żeby nie spalić portu ADC?
DC Converters
Main Programator/Debugger
UART
Vout = I*Rshunt*Gwzm 3.3 = 1 * Rsh * 50 Rsh = 3.3/50 = 66mOhm dla Rsh = 50 mOhm - max 2,5 V P = I^2*R = 1*0,050 = 0.05W
USB C Source
Converter
1%tolerance
8.4V
Additional power port
Panel fotowoltaiczny, Zasilacz DC
termal pad, multiple vias
czy dwa wyjscia mozna połączyć OUT A B
BMS
Power Supply

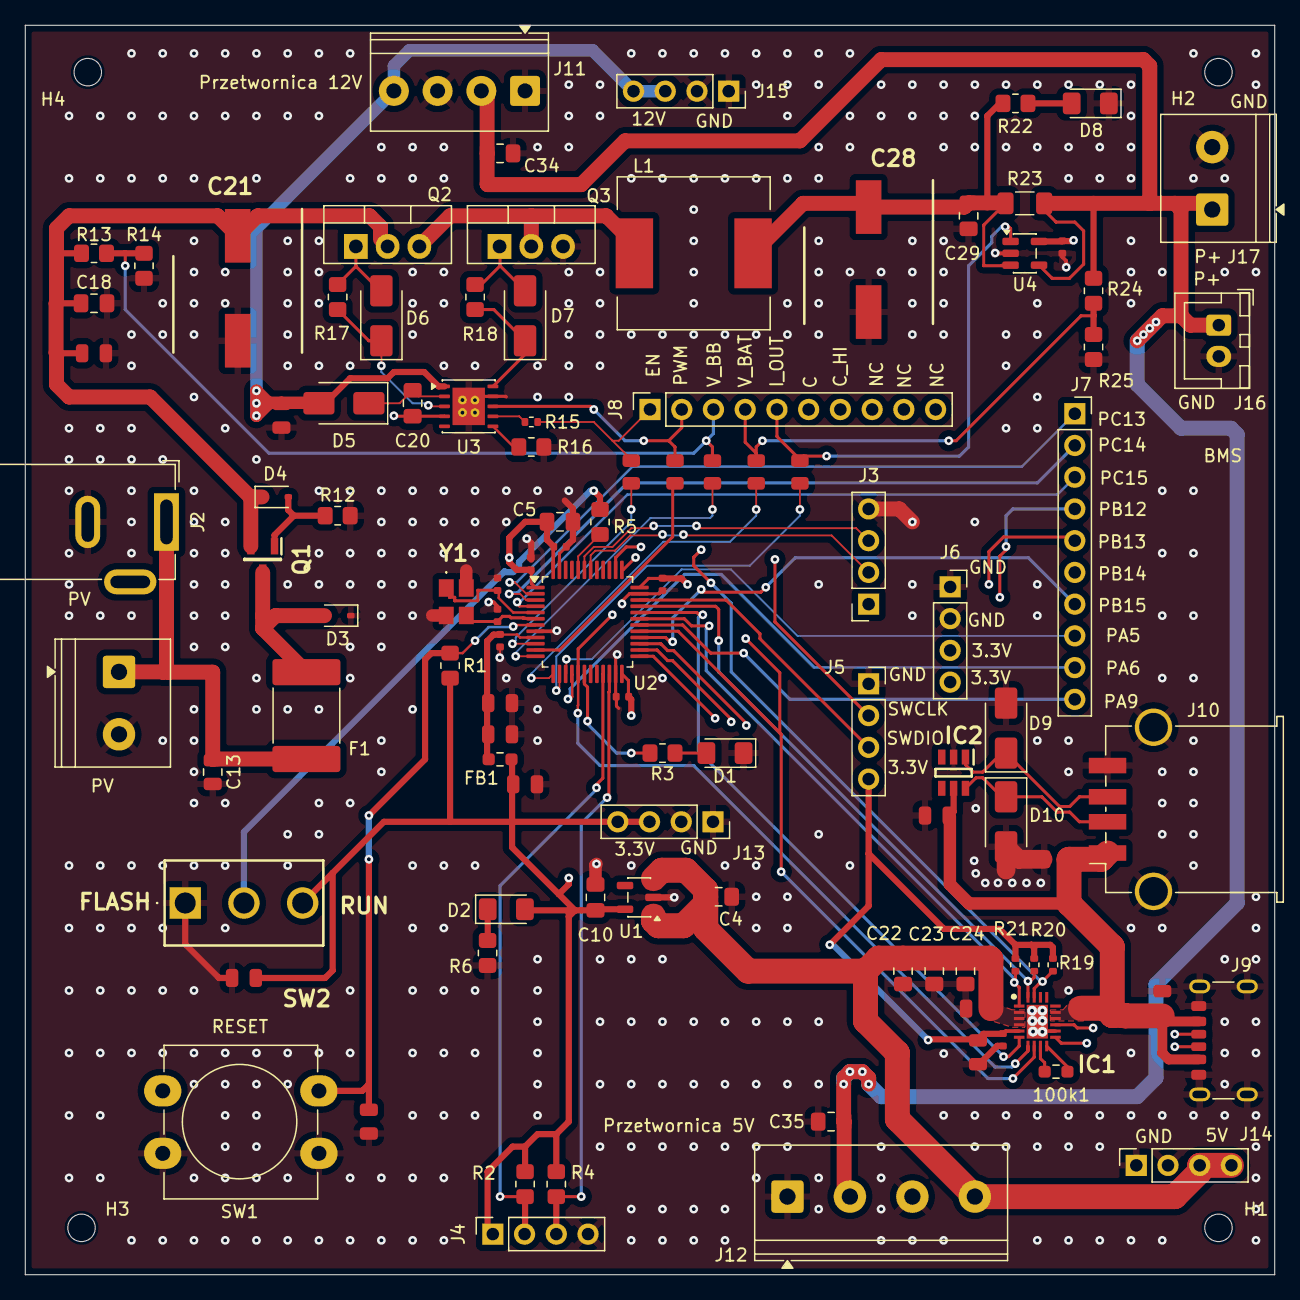
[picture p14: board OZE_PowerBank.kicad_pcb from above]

Board: 4 copper layers, 100.0 x 100.0 mm, 107 parts (0 on the bottom side), 67 nets.

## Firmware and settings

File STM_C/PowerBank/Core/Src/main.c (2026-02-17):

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
/* Includes ------------------------------------------------------------------*/
#include "main.h"

/* USER CODE BEGIN Includes */
#include <stdio.h>
#include <stdlib.h>
#include <string.h>
/* USER CODE END Includes */

/* USER CODE BEGIN PD */
// Limity baterii Li-Ion 2s (Nominal 7.4V)
#define MAX_V_IN		30.0f	// [V] Max napięcie wejściowe
#define MAX_V_OUT       8.40f   // [V] Max napięcie (CV cut-off)
#define MAX_I_OUT       1.80f   // [A] Max prąd ładowania (CC limit)
#define MIN_V_IN_OFFSET 1.50f   // [V] O ile Vin musi być wyższe od Vout, aby startować
#define MIN_V_BAT_SAFE  5.50f   // [V] Poniżej tego napięcia bateria może być uszkodzona

// Kalibracja ADC
#define ADC_SCALE_VIN   0.008f  // Przelicznik RAW ADC -> Volty dla wejścia
#define ADC_SCALE_VOUT  0.003f  // Przelicznik RAW ADC -> Volty dla wyjścia
#define ADC_SCALE_IOUT  0.0008f  // Przelicznik RAW ADC -> Ampery

// Ustawienia PWM
#define PWM_PERIOD      639    // ARR timera
#define MAX_DUTY        607     // 95% max wypełnienie (dla bootstrapu drivera)
#define MIN_DUTY        0       // 0%

// Ustawienia bufora DMA
#define ADC_CHANNELS    3   // Vin, Vout, Iout
#define DMA_SAMPLES     10  // Ilość próbek na kanał

// Współczynnik filtra dolnoprzepustowego (0.0 do 1.0).
#define FILTER_ALPHA_V  0.3f  // Dla napięć (zazwyczaj stabilniejsze)
#define FILTER_ALPHA_I  0.3f  // Dla prądu (wymaga mocniejszego tłumienia)
/* USER CODE END PD */

ADC_HandleTypeDef hadc1;
DMA_HandleTypeDef hdma_adc1;

TIM_HandleTypeDef htim2;

UART_HandleTypeDef huart1;

/* USER CODE BEGIN PV */
typedef struct {
	// --- Dane PRECYZYJNE (po filtrze EMA) ---
	// Używane do algorytmu MPPT i utrzymywania napięcia (CC-CV)
	float v_in;
	float v_out;
	float i_out;
	float power_out;
	float power_prev;

	// --- Dane NATYCHMIASTOWE (tylko średnia z DMA, bez EMA) ---
	// Używane do szybkiego wykrywania zwarć i przepięć
	float v_in_inst;
	float v_out_inst;
	float i_out_inst;
} SystemState;

SystemState sys;

uint16_t duty_cycle = 0; // Aktualne wypełnienie (0 - PWM_PERIOD)
int8_t mppt_direction = 1; // 1 = zwiększamy duty, -1 = zmniejszamy

// Flagi stanu
typedef enum {
    STATE_IDLE,
    STATE_SOFT_START,
    STATE_CHARGING,
    STATE_ERROR
} ChargerState;

ChargerState current_state = STATE_IDLE;

// Bufor DMA: [Vin1, Vout1, Iout1, Vin2, Vout2, Iout2, ... Vin20, Vout20, Iout20]
volatile uint32_t adc_dma_buffer[ADC_CHANNELS * DMA_SAMPLES];

/* USER CODE END PV */

void SystemClock_Config(void);
static void MX_GPIO_Init(void);
static void MX_DMA_Init(void);
static void MX_USART1_UART_Init(void);
static void MX_ADC1_Init(void);
static void MX_TIM2_Init(void);
/* USER CODE BEGIN PFP */
int __io_putchar(int ch);
void HAL_GPIO_EXTI_CALLBACK(uint16_t GPIO_Pin);
void Calc_ADC(void);
void Control_Loop(void);
void Set_PWM_Duty(uint16_t duty);
void Buck_Enable(uint8_t enable);
float Filter_EMA(float current_val, float prev_val, float alpha);
void Log_Status(void);
/* USER CODE END PFP */

/**
  * @brief  The application entry point.
  * @retval int
  */
int main(void)
{

  /* MCU Configuration--------------------------------------------------------*/

  /* Reset of all peripherals, Initializes the Flash interface and the Systick. */
  HAL_Init();

  /* Configure the system clock */
  SystemClock_Config();

  /* Initialize all configured peripherals */
  MX_GPIO_Init();
  MX_DMA_Init();
  MX_USART1_UART_Init();
  MX_ADC1_Init();
  MX_TIM2_Init();
  /* Infinite loop */
  /* USER CODE BEGIN WHILE */
  uint32_t control_timer = 0;
  uint32_t log_timer = 0;

  HAL_ADCEx_Calibration_Start(&hadc1);
  HAL_ADC_Start_DMA(&hadc1, (uint32_t*)adc_dma_buffer, ADC_CHANNELS * DMA_SAMPLES); //Inicjalizacja DMA do pomiarów ADC na V_BB, V_BAT, I_OUT
  HAL_TIM_PWM_Start(&htim2,TIM_CHANNEL_2);
  Buck_Enable(0); //Domyślnie ENABLE dla BUCK na 0
  HAL_GPIO_WritePin(ENABLE_TPS_GPIO_Port,ENABLE_TPS_Pin, GPIO_PIN_RESET); //Domyślnie ENABLE_TPS dla USB na 0

  while (1)
  {
	  // Pętla 100Hz - Zarządzanie logiką
	  if (HAL_GetTick() - control_timer >= 10)
	  {
		  control_timer = HAL_GetTick();

		  Calc_ADC();
		  Control_Loop();
	  }

	  // Pętla 1Hz - Dane pomiarowe(logs)
	  if(HAL_GetTick() - log_timer >= 1000){
		  log_timer = HAL_GetTick();

		  Log_Status();
		  // Migająca dioda
		  HAL_GPIO_TogglePin(BLUE_D_GPIO_Port, BLUE_D_Pin);
	  }

    /* USER CODE END WHILE */

    /* USER CODE BEGIN 3 */
  }
  /* USER CODE END 3 */
}

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
/* USER CODE BEGIN 4 */

// Przekierowanie wyjścia print na UART //
int __io_putchar(int ch) // print -> UART
{
    if (ch == '\n') {
        uint8_t ch2 = '\r';
        HAL_UART_Transmit(&huart1, &ch2, 1, HAL_MAX_DELAY);
    }
    HAL_UART_Transmit(&huart1, (uint8_t*)&ch, 1, HAL_MAX_DELAY);
    return 1;
}

// Obsługa przerwań //
void HAL_GPIO_EXTI_CALLBACK(uint16_t GPIO_Pin){ // obsługa przerwań (USB - FAULT)
	if (GPIO_Pin == FAULT_Pin){
		HAL_GPIO_WritePin(FAULT_GPIO_Port, FAULT_Pin, GPIO_PIN_RESET);
		printf("FAULT!!!\n");
	}
}

// Logika kontroli ładowania Li-ion w układzie synchornicznego buck-convertera //
void Calc_ADC(void){
	//Przeliczanie jednostek na wartości mierzone
	uint32_t sum_vin = 0;
	uint32_t sum_vout = 0;
	uint32_t sum_iout = 0;

	// KROK 1: Sumowanie danych z bufora DMA
	// Bufor jest przeplatany: [CH0, CH1, CH2, CH0, CH1, CH2...]
	for (int i = 0; i < DMA_SAMPLES; i++) {
		sum_vin  += adc_dma_buffer[(i * ADC_CHANNELS) + 0]; // Rank 1: Vin
		sum_vout += adc_dma_buffer[(i * ADC_CHANNELS) + 1]; // Rank 2: Vout
		sum_iout += adc_dma_buffer[(i * ADC_CHANNELS) + 2]; // Rank 3: Iout
	}

	// Oblicz średnią surową (Raw)
	float raw_vin_avg  = (float)sum_vin / DMA_SAMPLES;
	float raw_vout_avg = (float)sum_vout / DMA_SAMPLES;
	float raw_iout_avg = (float)sum_iout / DMA_SAMPLES;

	// Konwersja na jednostki fizyczne
	float inst_vin  = raw_vin_avg * ADC_SCALE_VIN;
	float inst_vout = raw_vout_avg * ADC_SCALE_VOUT;
	float inst_iout = raw_iout_avg * ADC_SCALE_IOUT;

	sys.v_in_inst  = inst_vin;
	sys.v_out_inst = inst_vout;
	sys.i_out_inst = inst_iout;

	// KROK 2: Filtracja EMA (To nadal warto zostawić!)
	// DMA wygładza szum "szybki" (wysokoczęstotliwościowy),
	// EMA wygładza "pływanie" (niskoczęstotliwościowe).

	static uint8_t first_run = 1;
	if (first_run) {
		sys.v_in = inst_vin;
		sys.v_out = inst_vout;
		sys.i_out = inst_iout;
		first_run = 0;
	} else {
		sys.v_in  = Filter_EMA(inst_vin, sys.v_in, FILTER_ALPHA_V);
		sys.v_out = Filter_EMA(inst_vout, sys.v_out, FILTER_ALPHA_V);
		sys.i_out = Filter_EMA(inst_iout, sys.i_out, FILTER_ALPHA_I);
	}

	// Obliczenie mocy
	sys.power_out = sys.v_in * sys.i_out;
}

void Control_Loop(void) {
    // Zabezpieczenia nadrzędne (HARD LIMITS)
	// Over-Voltage Protection (OVP) - margines bezpieczeństwa np. +0.3V
    if (sys.v_out_inst > (MAX_V_OUT + 0.2f)) {
        // Krytyczne przeładowanie - natychmiast STOP
        Buck_Enable(0);
        duty_cycle = 0;
        Set_PWM_Duty(0);
        current_state = STATE_ERROR;
        return;
    }

    // Over-Voltage Protection (OVP) - wejścia > MAX_V_IN
    if (sys.v_in_inst > MAX_V_IN) {
            // Krytyczna wartość napięcia wejściowego - natychmiast STOP
            Buck_Enable(0);
            duty_cycle = 0;
            Set_PWM_Duty(0);
            current_state = STATE_ERROR;
            return;
        }

    // Over-Current Protection (OCP) - margines np. +0.5A ponad limit
        if (sys.i_out_inst > (MAX_I_OUT + 0.3f)) {
            Buck_Enable(0);
            duty_cycle = 0;
            Set_PWM_Duty(0);
            current_state = STATE_ERROR;
            return;
        }

    // Maszyna stanów
    switch (current_state) {
        case STATE_IDLE:
            duty_cycle = 0;
            Buck_Enable(0);

            // Warunek startu: Słońce świeci (Vin > Vbat + margines)
            if (sys.v_in > (sys.v_out + MIN_V_IN_OFFSET) && sys.v_out > MIN_V_BAT_SAFE) {
                current_state = STATE_SOFT_START;
                Buck_Enable(1);
                duty_cycle = (sys.v_out/sys.v_in)*PWM_PERIOD - 30; // Wartość progowa dla, której V_buck = V_bat
            }
            break;

        case STATE_SOFT_START:
            // Powolne narastanie prądu, aby nie uszkodzić wejścia/wyjścia

            duty_cycle += 1; // Powoli zwiększaj
            if (sys.i_out > 0.1f) { // Jeśli prąd popłynął
                current_state = STATE_CHARGING;
            }
            // Zabezpieczenie powrotu
            if (sys.v_in <= sys.v_out + MIN_V_IN_OFFSET) current_state = STATE_IDLE;
            break;

        case STATE_CHARGING:
            /*
             * ALGORYTM HYBRYDOWY MPPT + CC/CV
             * Priorytety:
             * 1. Nie przekraczaj napięcia MAX (CV)
             * 2. Nie przekraczaj prądu MAX (CC)
             * 3. Jeśli powyższe OK -> Szukaj punktu mocy (MPPT P&O)
             */

            // --- REGULATOR OGRANICZEŃ (LIMITER) ---
            int limit_active = 0;

            // Ograniczenie napięciowe (CV - Constant Voltage)
            if (sys.v_out >= MAX_V_OUT) {
                if (duty_cycle > 0) duty_cycle--; // Zmniejsz duty
                limit_active = 1;
            }
            // Histereza CV (delikatne podejście)
            else if (sys.v_out > (MAX_V_OUT - 0.05f)) {
                 // Nie zwiększaj duty w strefie bliskiej max
                 limit_active = 1;
            }

            // Ograniczenie prądowe (CC - Constant Current)
            if (sys.i_out >= MAX_I_OUT) {
                if (duty_cycle > 0) duty_cycle--; // Zmniejsz duty
                limit_active = 1;
            }

            // --- ALGORYTM MPPT (Perturb & Observe) ---
            // Działa tylko wtedy, gdy nie uderzamy w limity baterii
            if (!limit_active) {
                // Czy moc wzrosła?
                if (sys.power_out > sys.power_prev) {
                    // Tak: idziemy dalej w tym samym kierunku
                    duty_cycle += mppt_direction;
                } else {
                    // Nie: moc spadła, zmieniamy kierunek
                    mppt_direction = -mppt_direction;
                    duty_cycle += mppt_direction;
                }

                sys.power_prev = sys.power_out;
            }

            // Sprawdzenie "Under Voltage Lockout" dla panelu
            if (sys.v_in < sys.v_out + MIN_V_IN_OFFSET) {
                current_state = STATE_IDLE;
                break;
            }

            // Sprawdzenie czy nie odłączono akumulatorów
            if (sys.v_out <= MIN_V_BAT_SAFE){
            	current_state = STATE_IDLE;
            	break;
            }

            if(sys.i_out < 0.01f){
            	current_state = STATE_IDLE;
            }
            break;


        case STATE_ERROR:
            // Wymaga resetu lub histerezy powrotu
            if (sys.v_out_inst < MAX_V_OUT - 0.5f && sys.v_in_inst < MAX_V_IN - 1.0f){
                current_state = STATE_IDLE;
            }
            break;

    }

    // Zastosuj Duty Cycle z limitem Hard-Hardware
    if (duty_cycle > MAX_DUTY) duty_cycle = MAX_DUTY;
    if (duty_cycle < MIN_DUTY) duty_cycle = MIN_DUTY;

    Set_PWM_Duty(duty_cycle);
}

// Najważniejsze dane - logs
void Log_Status(void) {
    // Konwersja stanu na napis
    char state_str[10];
    switch (current_state) {
        case STATE_IDLE:       sprintf(state_str, "IDLE"); break;
        case STATE_SOFT_START: sprintf(state_str, "SOFT"); break;
        case STATE_CHARGING:   sprintf(state_str, "CHRG"); break;
        case STATE_ERROR:      sprintf(state_str, "ERR!"); break;
        default:               sprintf(state_str, "????"); break;
    }

    printf("[State: %s] Vin: %5.2fV | Vout: %5.2fV | Iout: %5.2fA | Pwr: %5.2fW | PWM: %3d | I_out_inst: %5.3fA \n",
           state_str,
           sys.v_in,
           sys.v_out,
           sys.i_out,
           sys.power_out*((float)duty_cycle/PWM_PERIOD),
           duty_cycle, sys.i_out_inst);
}

/**
 * @brief  Cyfrowy filtr dolnoprzepustowy (EMA)
 * @param  current_val: nowa zmierzona wartość
 * @param  prev_val: poprzednia przefiltrowana wartość (historia)
 * @param  alpha: współczynnik wygładzania (0.0 - 1.0)
 * @return Nowa przefiltrowana wartość
 */
float Filter_EMA(float current_val, float prev_val, float alpha) {
    return (alpha * current_val) + ((1.0f - alpha) * prev_val);
}

void Set_PWM_Duty(uint16_t duty) {
    __HAL_TIM_SET_COMPARE(&htim2, TIM_CHANNEL_2, duty);
}

void Buck_Enable(uint8_t enable) {
    HAL_GPIO_WritePin(ENABLE_GPIO_Port, ENABLE_Pin, enable ? GPIO_PIN_SET : GPIO_PIN_RESET);
}
/* USER CODE END 4 */
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


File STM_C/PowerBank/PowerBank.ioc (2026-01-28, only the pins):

Mcu.UserName=STM32F103C8Tx
PA0-WKUP.GPIO_Label=ENABLE
PA0-WKUP.Signal=GPIO_Output
PA1.GPIO_Label=PWM
PA1.Signal=S_TIM2_CH2
PA10.GPIO_Label=FAULT
PA10.Signal=GPXTI10
PA11.GPIO_Label=ENABLE_TPS
PA11.Signal=GPIO_Output
PA12.GPIO_Label=LD_DET
PA12.Signal=GPIO_Input
PA13.Signal=SYS_JTMS-SWDIO
PA14.Signal=SYS_JTCK-SWCLK
PA15.GPIO_Label=UFP
PA15.Signal=GPIO_Input
PA2.GPIO_Label=V_BB
PA2.Signal=ADCx_IN2
PA3.GPIO_Label=V_BAT
PA3.Signal=ADCx_IN3
PA4.GPIO_Label=I_OUT
PA4.Signal=ADCx_IN4
PA7.GPIO_Label=CHG
PA7.Signal=GPIO_Input
PA8.GPIO_Label=CHG_HI
PA8.Signal=GPIO_Input
PB0.GPIO_Label=BLUE_D
PB0.Signal=GPIO_Output
PB6.Signal=USART1_TX
PB7.Signal=USART1_RX

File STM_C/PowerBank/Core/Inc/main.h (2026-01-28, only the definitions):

#define ENABLE_Pin GPIO_PIN_0
#define ENABLE_GPIO_Port GPIOA
#define PWM_Pin GPIO_PIN_1
#define PWM_GPIO_Port GPIOA
#define V_BB_Pin GPIO_PIN_2
#define V_BB_GPIO_Port GPIOA
#define V_BAT_Pin GPIO_PIN_3
#define V_BAT_GPIO_Port GPIOA
#define I_OUT_Pin GPIO_PIN_4
#define I_OUT_GPIO_Port GPIOA
#define CHG_Pin GPIO_PIN_7
#define CHG_GPIO_Port GPIOA
#define BLUE_D_Pin GPIO_PIN_0
#define BLUE_D_GPIO_Port GPIOB
#define CHG_HI_Pin GPIO_PIN_8
#define CHG_HI_GPIO_Port GPIOA
#define FAULT_Pin GPIO_PIN_10
#define FAULT_GPIO_Port GPIOA
#define FAULT_EXTI_IRQn EXTI15_10_IRQn
#define ENABLE_TPS_Pin GPIO_PIN_11
#define ENABLE_TPS_GPIO_Port GPIOA
#define LD_DET_Pin GPIO_PIN_12
#define LD_DET_GPIO_Port GPIOA
#define UFP_Pin GPIO_PIN_15
#define UFP_GPIO_Port GPIOA

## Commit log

2025-10-29 start
    start
    [Złożenie podpór .cfg, buck_converter.kicad_pcb, buck_converter.kicad_sch]
2025-11-03 merging files
    [buck_converter.kicad_pcb, buck_converter.kicad_sch]
2025-11-03 resoling issues
    [OZE_PowerBank.kicad_pcb, OZE_PowerBank.kicad_sch]
2025-11-03 STM project added
    [OZE_PowerBank.kicad_pcb, OZE_PowerBank.kicad_sch, Złożenie podpór .cfg]
2025-11-03 zabezpieczenia USB C
    [OZE_PowerBank.kicad_sch]
2025-11-04 04.11
    - 150uF kondensatory to elektrolity ważny LOW RMS!
    - Przetwornica do sterownika (IMZ Przetwornica MT3608 2A Step-Up DC/DC) gotowa płytka
    - 100 kHz sterowanie PWM (tak dobrany jest dławik i kondensatory co widać na symulacji)
    Symulacja w LT Spice
    [OZE_PowerBank.kicad_sch]
2025-11-04 BMS - 04.11 21:00 Hubert
    Dodany BMS wraz z tranzystorem odcinającym masę dla układu ładowania
    [OZE_PowerBank.kicad_sch]
2025-11-05 Update 05.11 19:00 - Hubert
    Zmiany:
    - oznaczenia zasilania na schemacie
    - dodano przetwornice buck down
    - dodano masę sygnałową ???
    - po przemieszanie elementów na schemacie (czytelniej)
    - zmiana kondensatorów odpowiednich na elektrolity (polarized)
    [OZE_PowerBank.kicad_sch]
2025-11-10 zmieniony symbol biblioteczny TPS, dodano footprinty, zmieniono piny wyprowadzeniowe, dodano opis funkci pinów STM , konfiguracja kanalow ADC
2025-11-10 added footprints, i have libraries localy, give comments about calculations of elements
    [OZE_PowerBank.kicad_sch]
2025-11-12 Zmiany na schemacie
    Zmiana wzmacniacza z INA180A2 na INA180A1 bo za duże napięcie wychodziło na wyjściu i wywaliłem symulacje bo bez niej nie moge dac commita
    [OZE_PowerBank.kicad_sch]
2025-11-13 added conectors footprints
    [OZE_PowerBank.kicad_pcb, OZE_PowerBank.kicad_sch]
2025-11-15 PCB layout
    [OZE_PowerBank.kicad_pcb, OZE_PowerBank.kicad_sch]
2025-11-15 before branching
    [OZE_PowerBank.kicad_pcb]
2025-11-26 26.11 Hubert - PCB
    Poprowadzone ścieżki sygnałowe, prądowe, poza 2 wchodzącymi do sterownika USB-C, USB-A . Brak wylanej masy
    [OZE_PowerBank.kicad_pcb, OZE_PowerBank.kicad_sch]
2025-11-27 Płytka PCB i ścieżki w zasadzie skończone 'prawie'
    Wylane warstwy, wszystkie połączenia poza dwoma od przycisku z których nie korzystamy, jeszcze są błędy jakieś związane z termal padami, ale juz możesz wprowadzać zmiany
    [OZE_PowerBank.kicad_pcb]
2025-11-28 changed footprint, correct GND conection to thermal, remove some vias, give additional vias in TPS25810
    [OZE_PowerBank-B_Cu.gbl, OZE_PowerBank-B_Mask.gbs, OZE_PowerBank-B_Paste.gbp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]
2026-01-28 Kod
    Całość konfiguracji STM32CubeMX i kod programu STM32CubeIDE
2026-02-17 Porządki związane z .gitignore
    [bom.csv, designators.csv, positions.csv]

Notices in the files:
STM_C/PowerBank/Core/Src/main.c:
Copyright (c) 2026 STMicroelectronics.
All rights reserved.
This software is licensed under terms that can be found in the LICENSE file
